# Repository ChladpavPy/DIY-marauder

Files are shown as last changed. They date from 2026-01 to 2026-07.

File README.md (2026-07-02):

# DIY Marauder

I have made this project because it was my first ever pcb project and I started with blueprint, I wanted something cool looking, like pentesting device for ethical hacking and as a experimental gadget that I could programm whatever way I wanted to do something cool and finally bring the code to life.

A custom macro keypad / pentesting node based on the Seeed XIAO ESP32S3 (originally designed for RP2040). Designed in KiCad and Fusion 360.

## Project Features

* **Microcontroller:** Seeed XIAO ESP32S3 (USB-C) *(Swapped from RP2040 due to delivery issues)*
* **Display:** 0.96" OLED (I2C) *(Swapped from 0.91")*
* **Controls:** 1x EC11 Rotary Encoder + 2x Mechanical MX Switches
* **Case:** Custom 3D printed snap-fit enclosure

## Gallery
### Build Preview
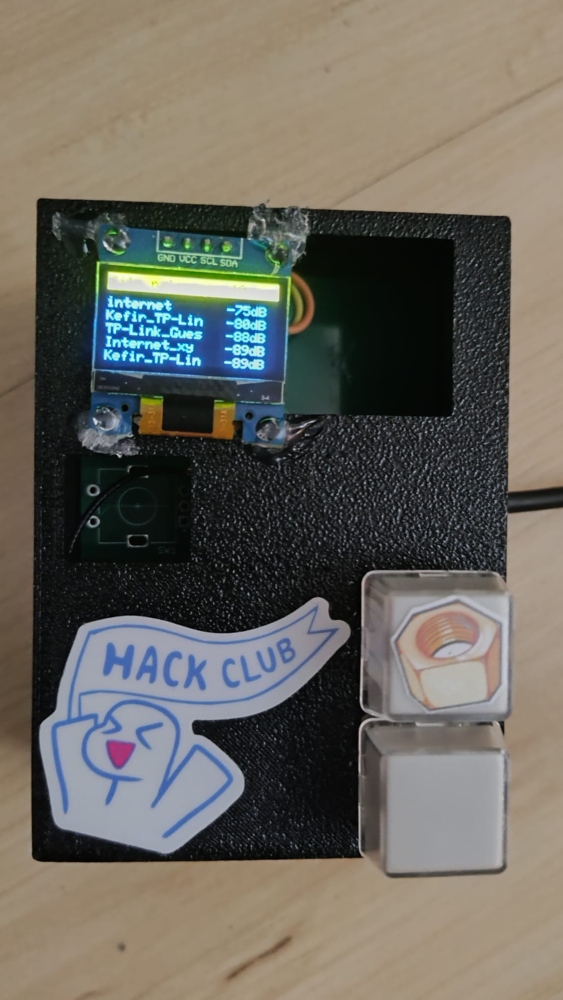
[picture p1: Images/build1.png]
Build preview

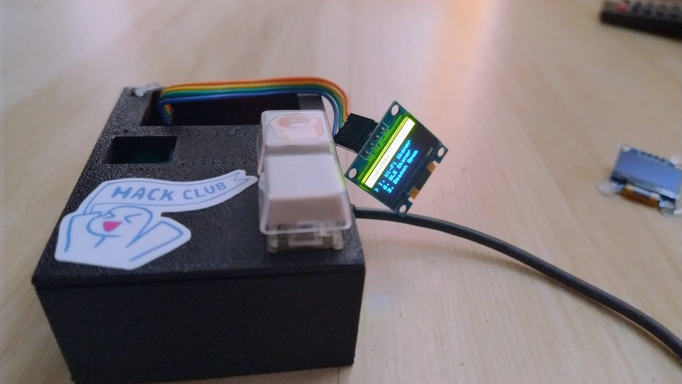
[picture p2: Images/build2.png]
Build preview

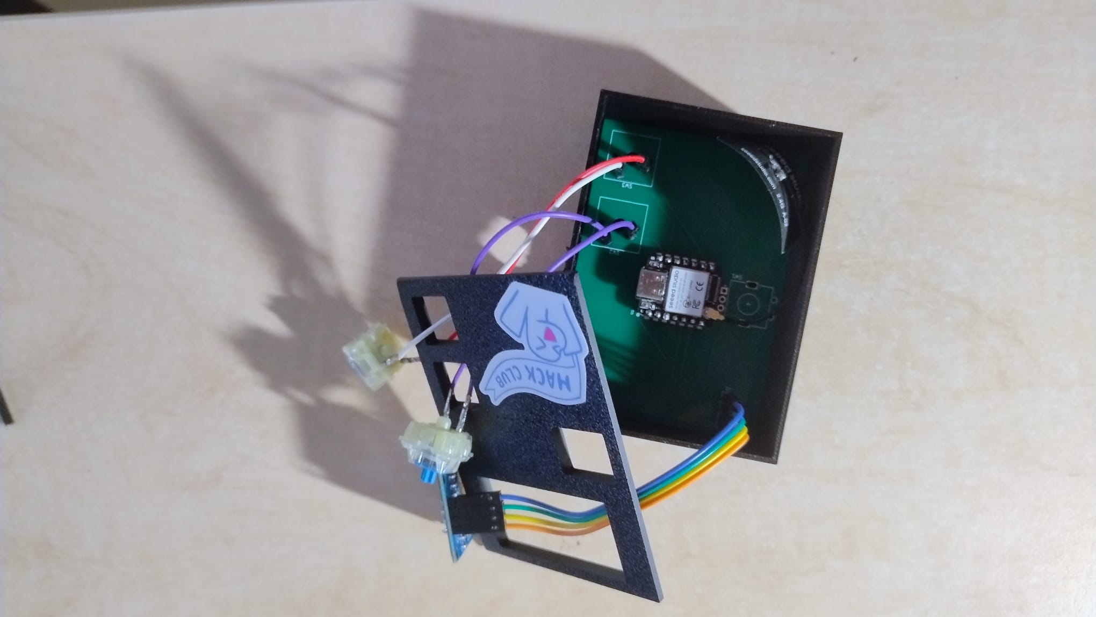
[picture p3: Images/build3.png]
Build preview


### Schematic
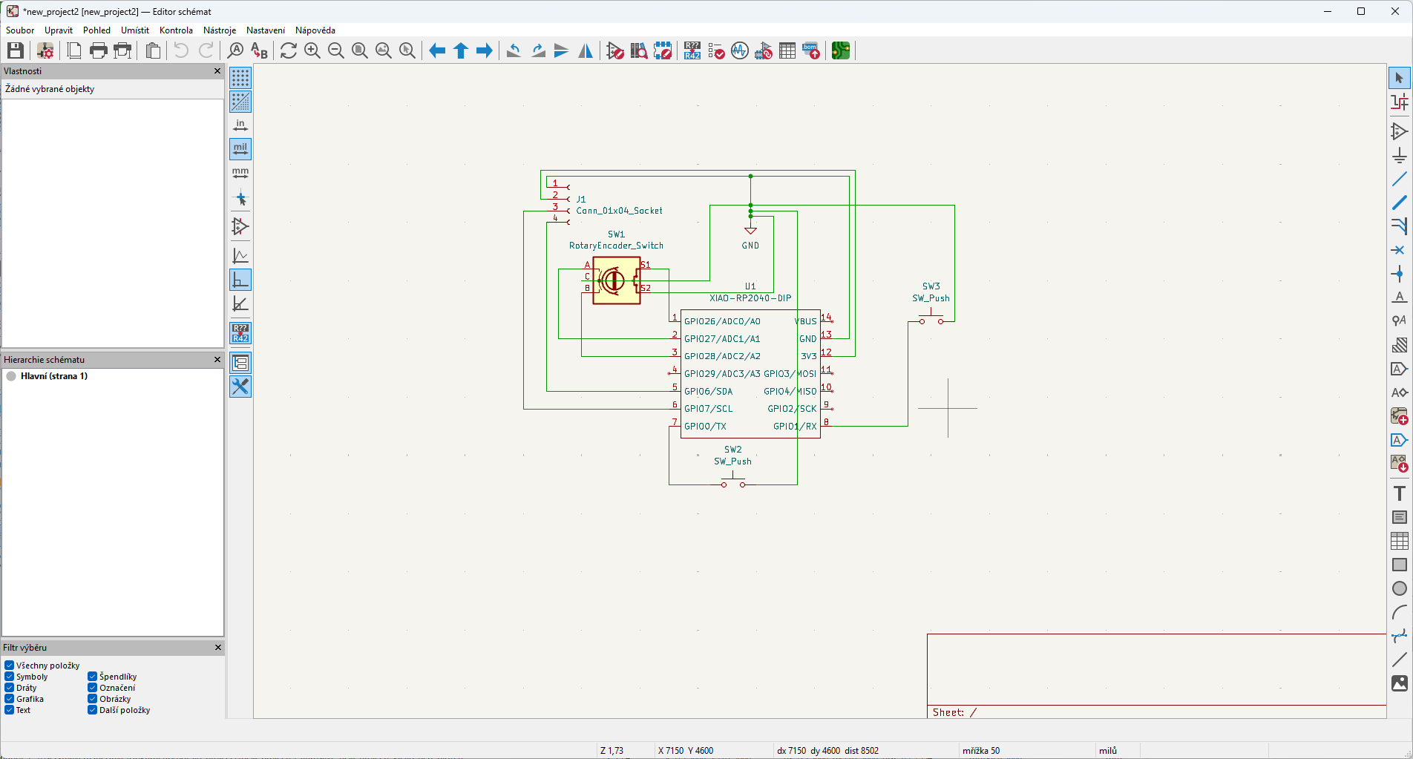
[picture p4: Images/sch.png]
Schematic


### PCB Routing
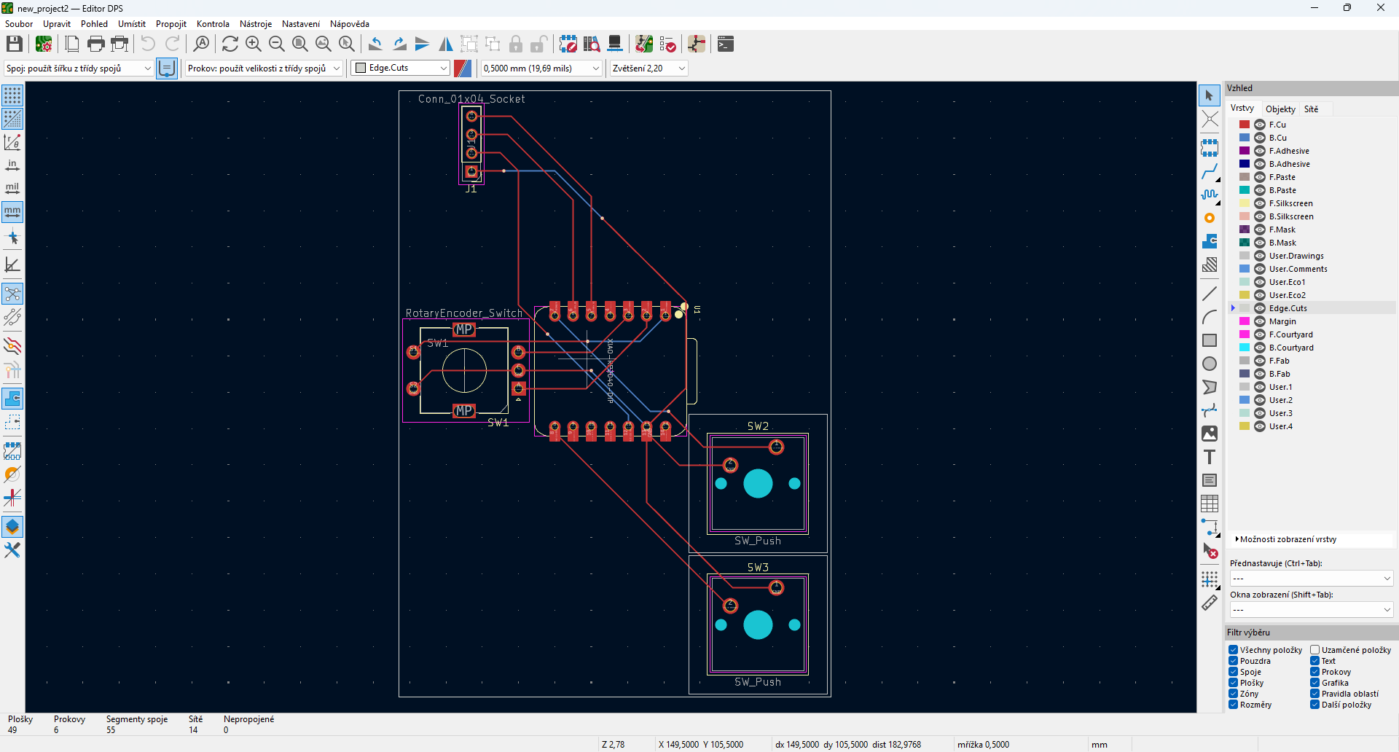
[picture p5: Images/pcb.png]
PCB 2D


### 3D PCB Render
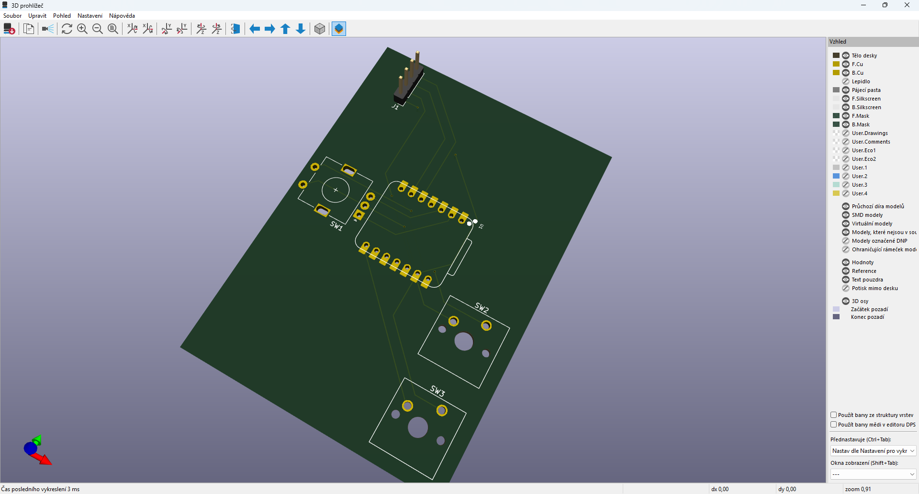
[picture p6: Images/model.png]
PCB 3D


### 3D Printed Case
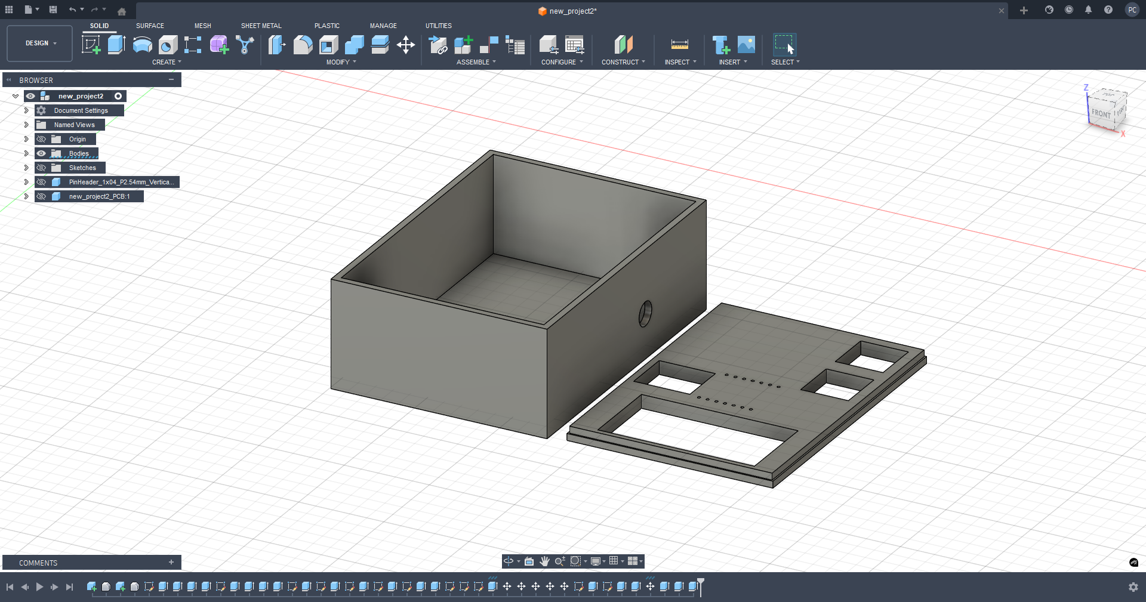
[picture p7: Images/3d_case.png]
Case


### Assembly Preview
The PCB fits perfectly inside the custom 3D printed case (designed with 0.4mm clearance).
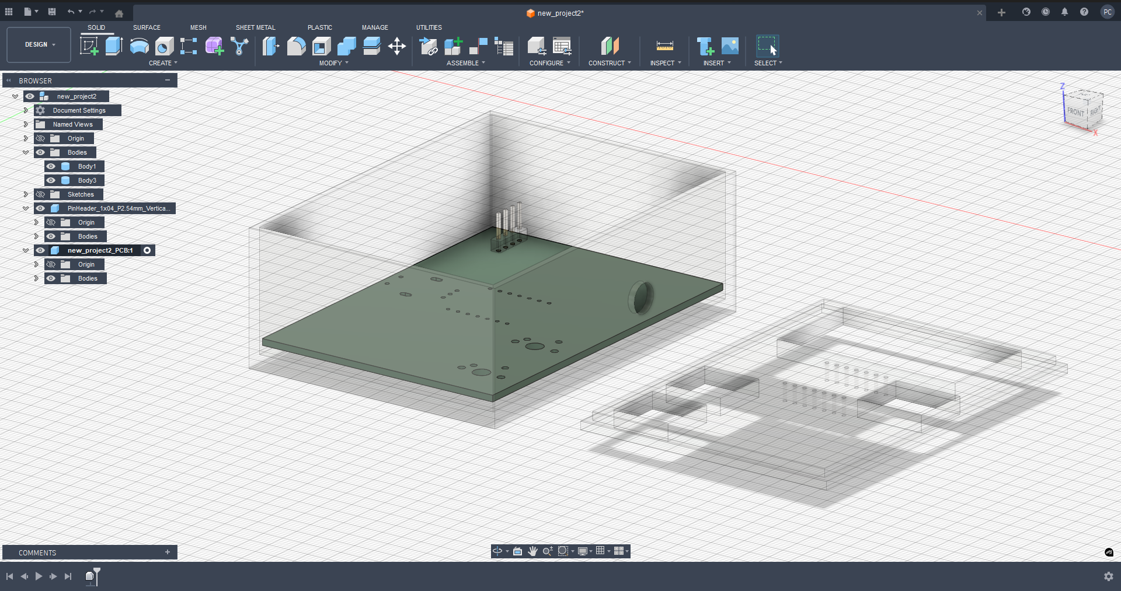
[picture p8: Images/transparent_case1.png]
Assembly Preview


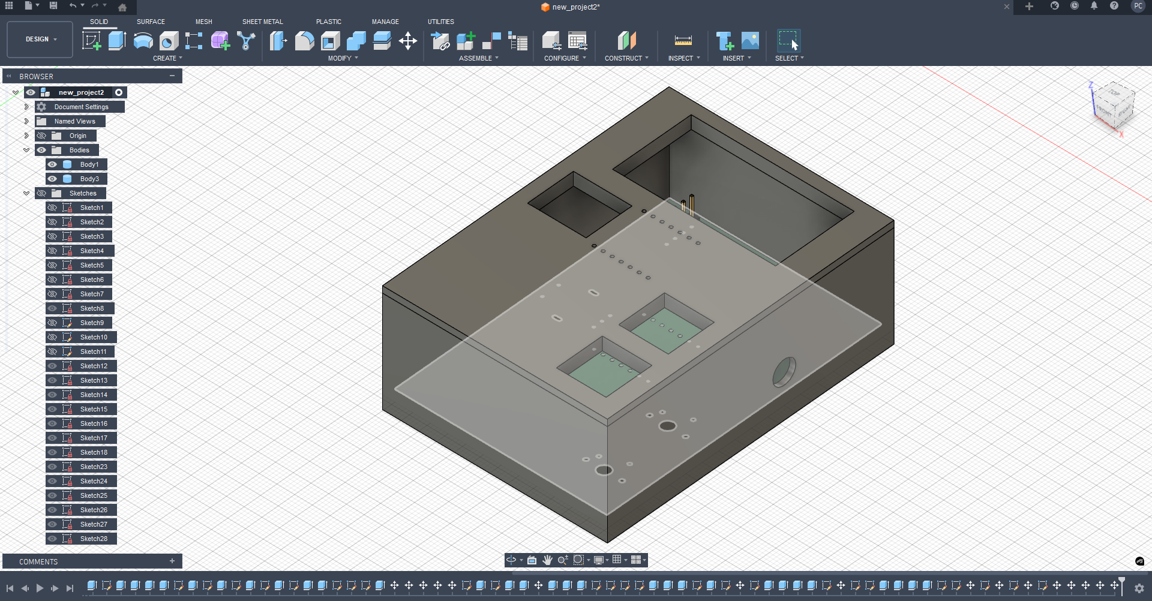
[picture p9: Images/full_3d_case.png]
Assembly_Preview2


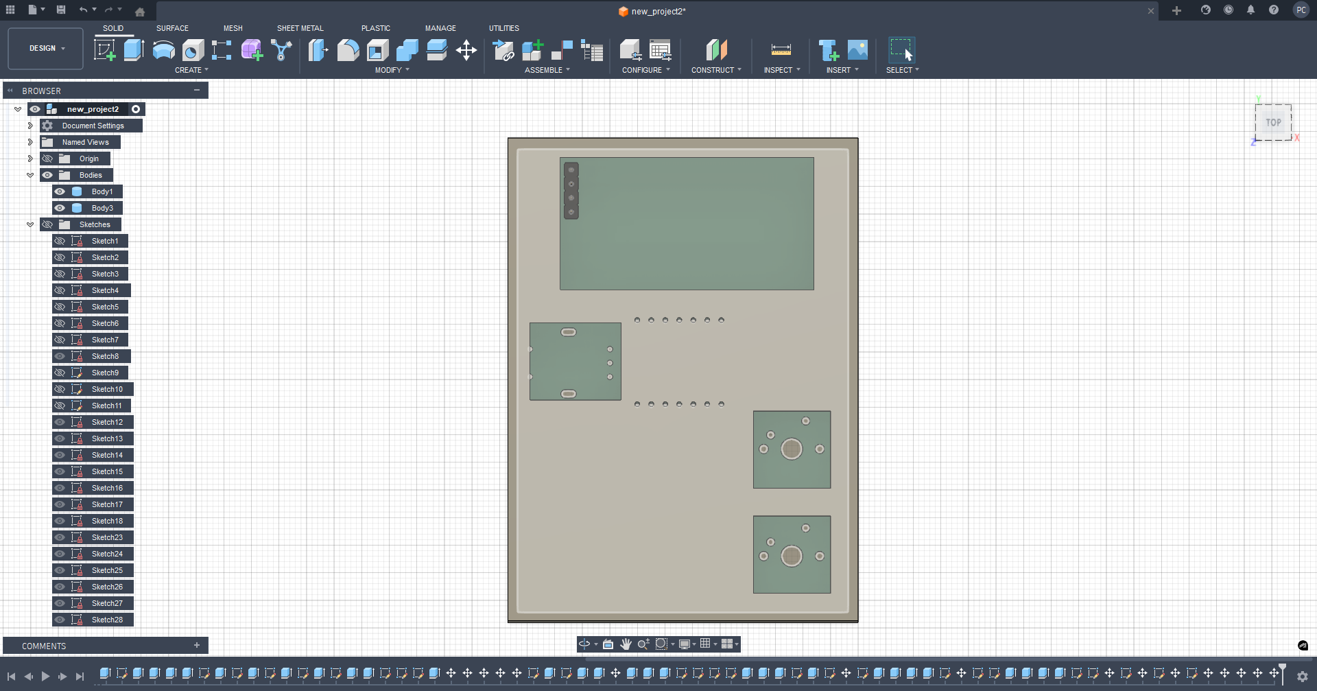
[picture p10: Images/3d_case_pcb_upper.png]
Assembly_Preview3


### Assembly Preview Seeed XIAO RP2040

Assembly Preview_xiao

Assembly Preview_xiao

Assembly Preview_xiao

Assembly Preview_xiao

Assembly Preview_xiao

Assembly Preview_xiao

---

Here is the updated BOM, previously I would have used XIAO RP2040, but since there was that customs delivery issues, I bought and used some of the remaining components from zeropad project

## Bill of Materials (BOM)

| Component | Qty | Purpose / Description | Price (USD) | Link / Distributor |
| :--- | :---: | :--- | :--- | :--- |
| **Seeed XIAO ESP32S3** | 1 | Microcontroller (Used instead of RP2040 due to delivery issues). | ~$7.50 | [Botland](https://botland.cz/moduly-wifi-a-bt-esp32/22878-seeed-xiao-esp32-s3-wifi-bluetooth-seeedstudio-113991114.html) |
| **0.96" I2C OLED Display** | 1 | Screen to show UI and analysis data (Swapped from 0.91"). | ~$2.00 | [AliExpress](https://a.aliexpress.com/_EGSrJ7g) |
| **EC11 Rotary Encoder** | 1 | Navigation control with push button. | ~$1.50 | [SparkFun](https://www.sparkfun.com/products/9117) |
| **Cherry MX Switches** | 2 | Secondary input buttons (Sourced from previous build). | ~$6.08 | [AliExpress](https://a.aliexpress.com/_EuLENRY) |
| **1U Blank Keycaps** | 2 | Standard covers for the mechanical switches. | ~$3.35 | [AliExpress](https://a.aliexpress.com/_Eyx6JJo) |
| **Knob** | 1 | Cap for the rotary encoder. | ~$1.50 | [SparkFun](https://www.sparkfun.com/products/10597) |
| **3D Printed Case** | 1 | Enclosure. Files in `3D_Models` folder. | $0.00 | printing legion |

---

## Folder Structure
* **Gerbers:** Manufacturing files ready for JLCPCB.
* **KiCad_Source:** Editable project files for KiCad.
* **3D_Models:** STL and STEP files for printing.

Journals - 
I am really sorry for the confusion, I thought that I was just submitting it for design review at first in stasis and I noticed it just now, however somehow it shows that it was submitted for build review, so I am adding the journals that I wanted to write in stasis there with time - I hope that it will be okay like this and also thank you for the review! : Journals - 

1. journal - soldering and first testing - 4 hours

Before that I have obviously spent a lot of time witch searching the cheapest esp32s3 xiao, which I could get, since these devices were not exatly cheap in czech republic or aliexpress and also wrote some firmware even before that although I still have not it working because I was still missing the keycaps and cherry mx switches which I used from the zeropad projet which arrived on monday, so I still had some time to build it.
I started by soldering everything. First I soldered the esp32-s3, but then I hit some major issues. I was struggling with how to mount the Cherry MX switches because the enclosure was so high and I needed them fixed at the top. It eventually hit me I could just place the switches in that top space and connect them from the bottom using jumper wires through the tht pads. So I soldered pin headers to the pcb on the bottom and then I soldered female jumpers to the switches and connected them. I did that twice.
After that I ran into another problem. Because of the postal service I did not have the encoder I ordered so I tried to scavenge one from around the house. I spent forever searching through the garage until I finally realized I could grab an encoder from an old grill. Finding the screwdriver to open it up in that messy garage was not easy but I managed to dismantle it only to realize it did not have any pins so it was absolutely useless. I just wasted my time.
Anyway I managed to get the display working. I used a pin header on the pcb and connected the screen via jumpers. After the hardware was somewhat assembled I had to actually make it do something useful. I did not want this to be just a simple script I wanted a standalone tool for network analysis. Since my plan to use a scavenged grill encoder failed I had to rely entirely on the two Cherry MX switches. This meant I could not just use a standard library for the menu so I had to write a custom UI system from scratch. I built a scrollable menu interface that dynamically adjusts to the oled screen. Writing a state machine for the button debouncing to handle both short and long presses took way more time than I expected but it was necessary to make the navigation feel responsive.
The firmware itself is around 1100 lines of c++ code. I implemented a wifi scanner and analyzer that scans 2.4ghz bands grabs rssi encryption types and mac addresses. I even added a visual channel analyzer to see where the interference is. Then I added a ble scanner to find bluetooth devices around and sort them by signal strength. Since this is meant to be portable I also implemented a deep sleep mode to save power when it is not actively scanning. Getting the display library to play nice with the specific i2c pins i routed on my pcb required some tweaking but once the display initialized it was satisfying.
Looking back considering this was my first pcb I did some pretty stupid things. I have no idea what I was thinking. First off I did not even realize i could use a gnd filled zone or plane so I just routed gnd traces everywhere but whatever it works. The real problem was the 3d case. For some reason I made a circular hole for the usb-c port not realizing I needed to fit the whole connector through it not just the cable. I literally just made a hole for the cable. Plus I placed the xiao in the middle of the board instead of at the edge so the usb-c port does not stick out properly which looks weird.
I had to fix the hole somehow. I tried sandpaper but that would have taken hours so I went for the radical solution. I grabbed a soldering iron and just ugly-melted the opening bigger despite breathing in all those plastic fumes. It did the trick and the cable fits now. Obviously I did not use my good soldering iron for that just an old destroyed one that was a year old anyway so it does not really matter.
Looking at the final build it is definitely a prototype. The hot glue and the missing encoder do not look professional but the core engineering is solid. I designed the pcb figured out the mechanical mounting for the switches and wrote a custom os for it. It works as a pocket-sized pentesting node. That wrapped up the soldering and assembly. I then started programming and testing the board but I will write about that in the next journal entry.

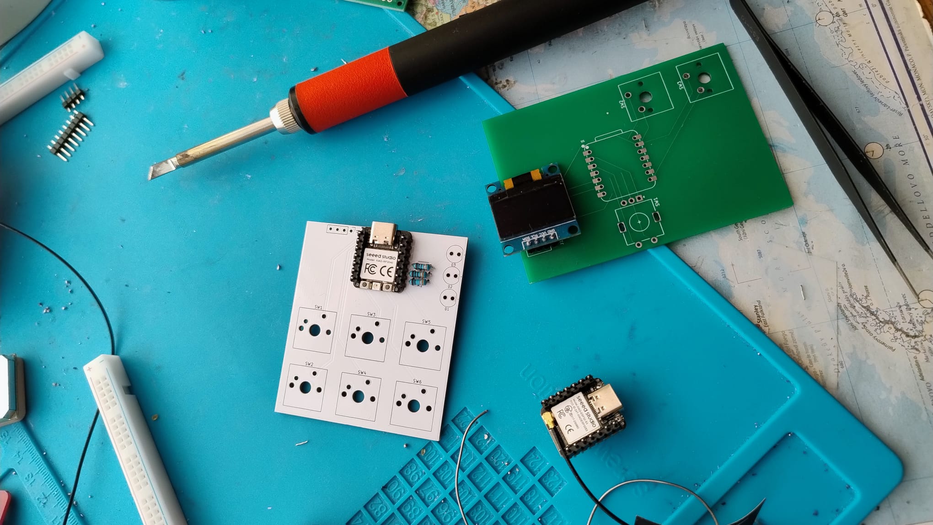
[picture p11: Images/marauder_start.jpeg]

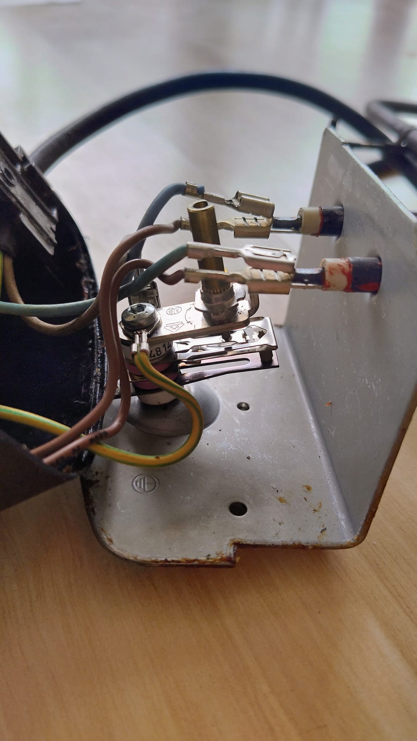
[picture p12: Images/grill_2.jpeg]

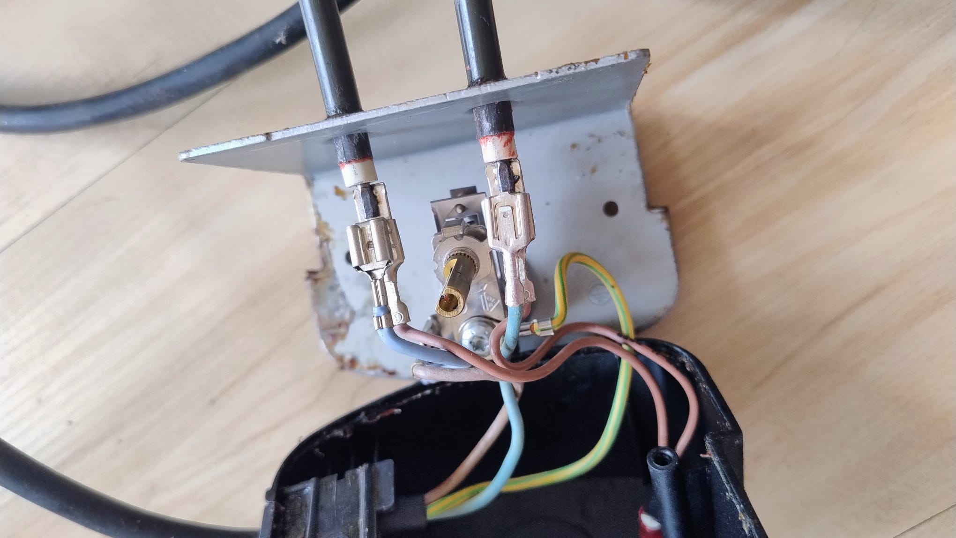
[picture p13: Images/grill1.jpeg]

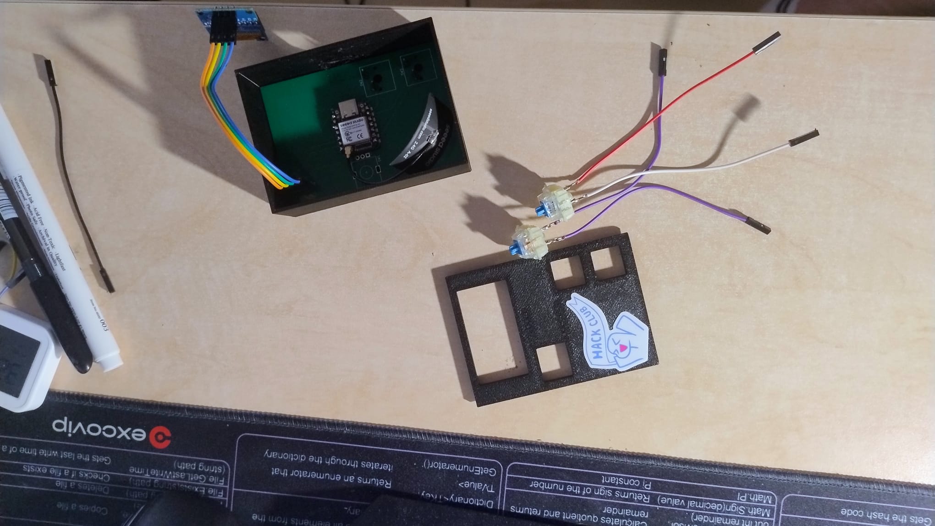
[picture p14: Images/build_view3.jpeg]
Build preview

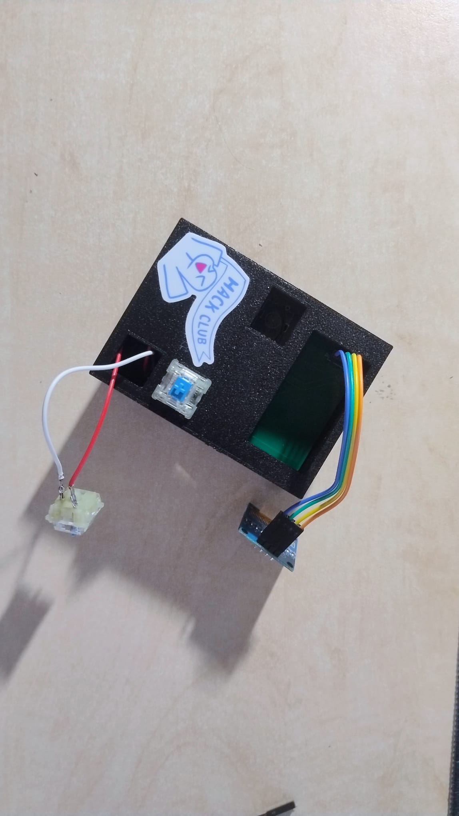
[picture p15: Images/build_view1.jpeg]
Build preview

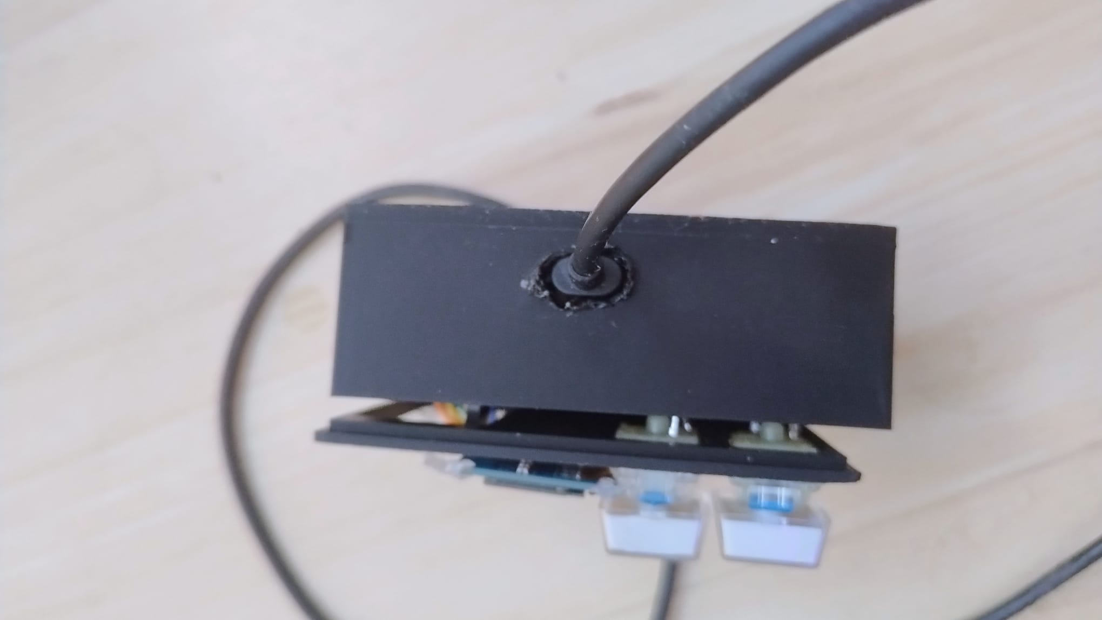
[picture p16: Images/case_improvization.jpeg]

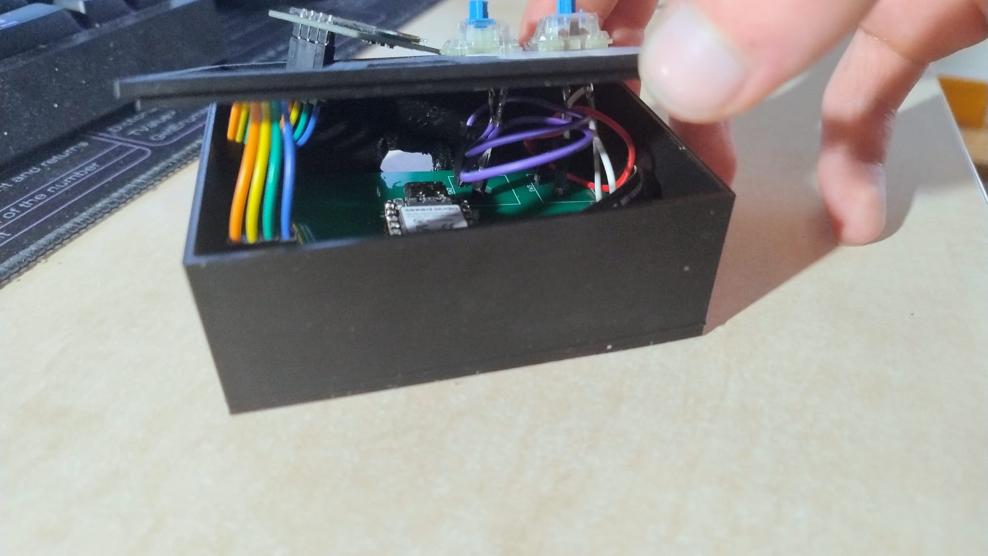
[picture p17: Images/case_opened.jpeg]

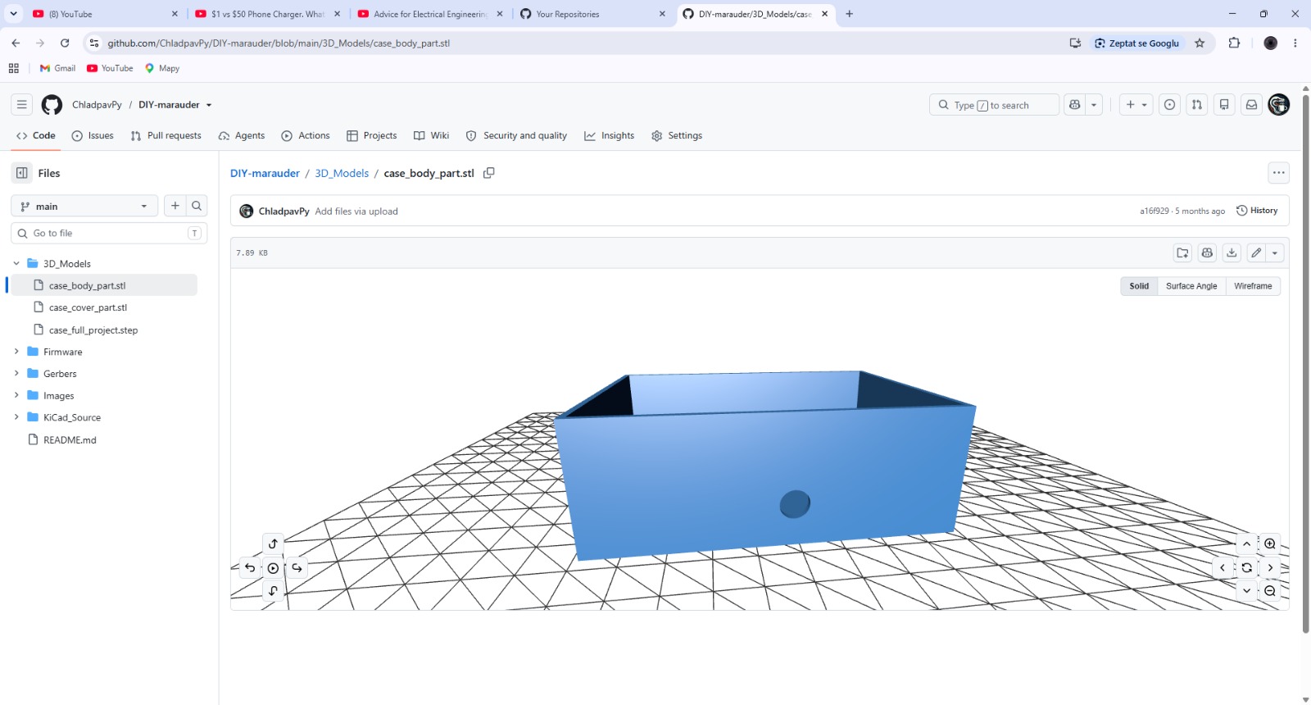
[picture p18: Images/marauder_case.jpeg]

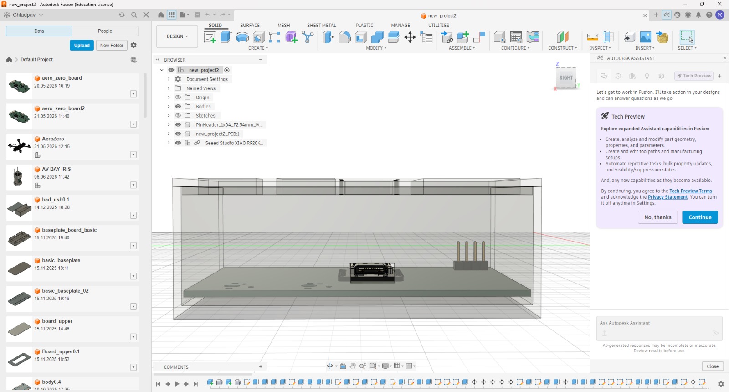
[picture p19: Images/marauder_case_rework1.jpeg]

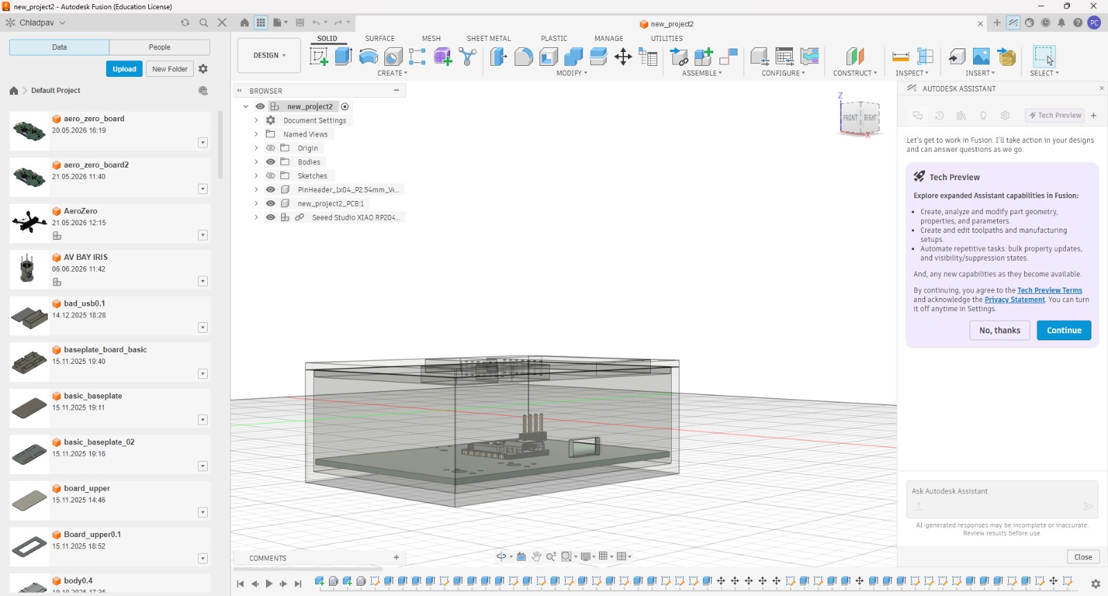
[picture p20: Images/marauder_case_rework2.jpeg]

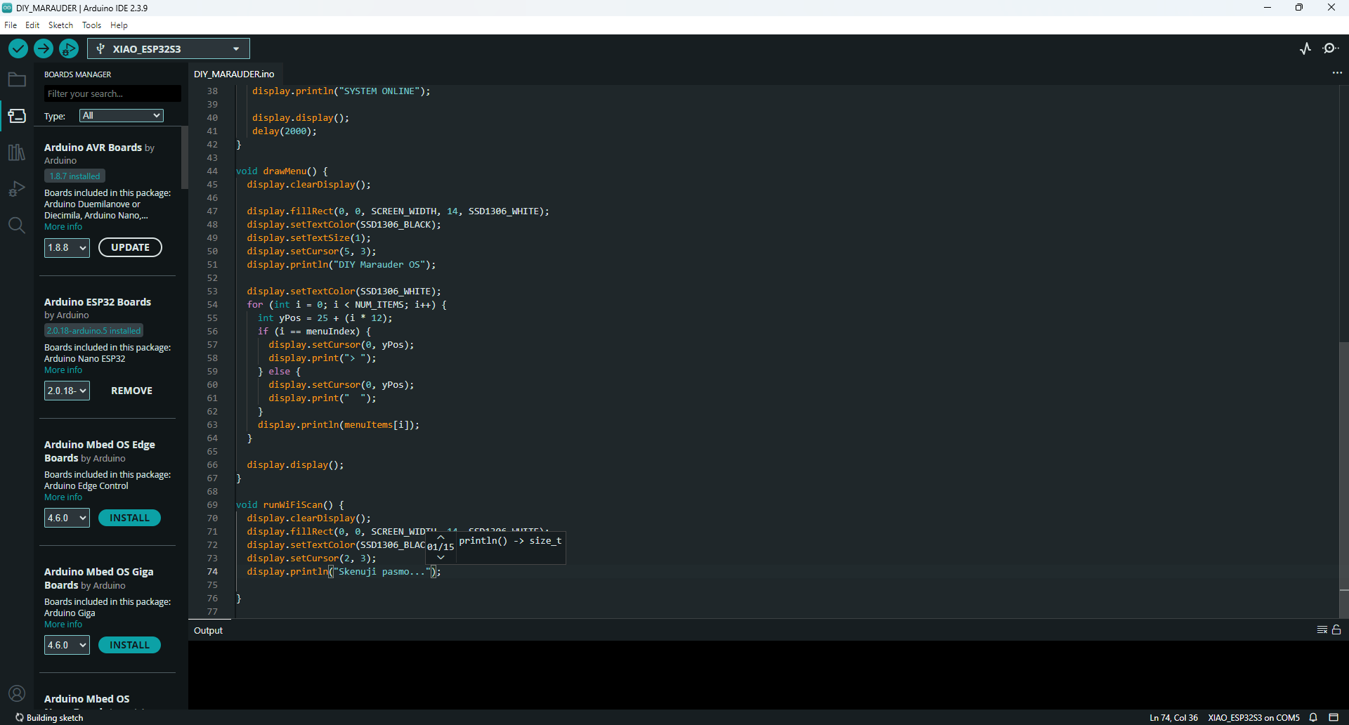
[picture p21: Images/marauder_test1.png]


2. journal - writing the firmware and flashing the device - 4 hours 20 minutes
After the hardware was somehow assembled, I had to actually make it do something useful. I did not want this to be just a simple script, I wanted a standalone tool for network analysis. Since my plan to use a scavenged grill encoder failed, I had to rely entirely on the two Cherry MX switches. This meant I could not just use a standard library for the menu, so I had to write a custom UI system from scratch. I built a scrollable menu interface that dynamically adjusts to the OLED screen. Writing a state machine for the button debouncing to handle both short and long presses took way more time than I expected, but it was necessary to make the navigation feel responsive.
The firmware itself is around 1100 lines of C++ code. I implemented a WiFi scanner and analyzer that scans 2.4GHz bands, grabs RSSI, encryption types and MAC addresses. I even added a visual channel analyzer to see where the interference is. Then I added a BLE scanner to find Bluetooth devices around and sort them by signal strength. Since this is meant to be portable, I also implemented a deep sleep mode to save power when it is not actively scanning. Getting the display library to play nice with the specific I2C pins I routed on my PCB required some tweaking, but once the display initialized, it was incredibly satisfying. Looking at the final build, it is definitely a prototype. The hot glue and the missing encoder do not look exactly professional, but the core engineering is solid. I designed the PCB, figured out the mechanical mounting for the switches, and wrote a completely custom OS for it. It works good as a pocket sized pentesting device and even integrated a encoder detection system since I have not got encoder to make it work although I dont have it. I am actually also really amazed what you can actually do with just a esp32 with just 7 pins and also with small 0.96 inch display
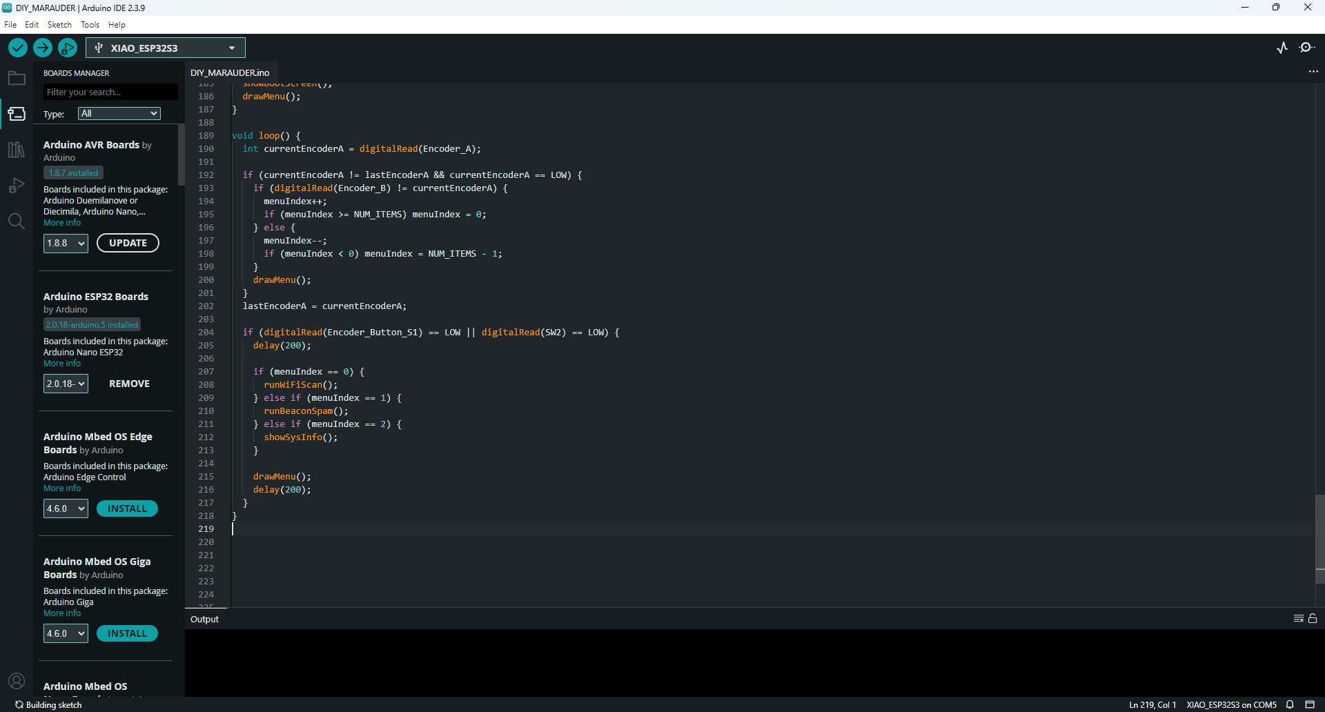
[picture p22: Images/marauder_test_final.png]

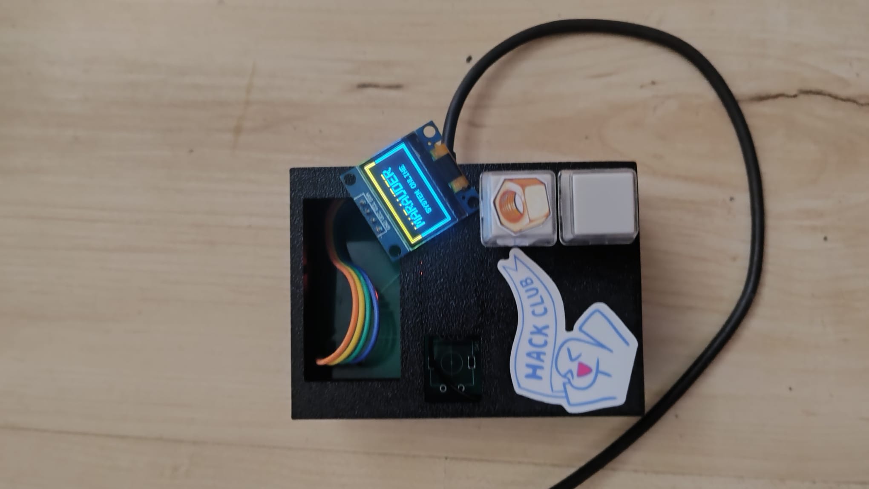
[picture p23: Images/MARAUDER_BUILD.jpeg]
Build preview

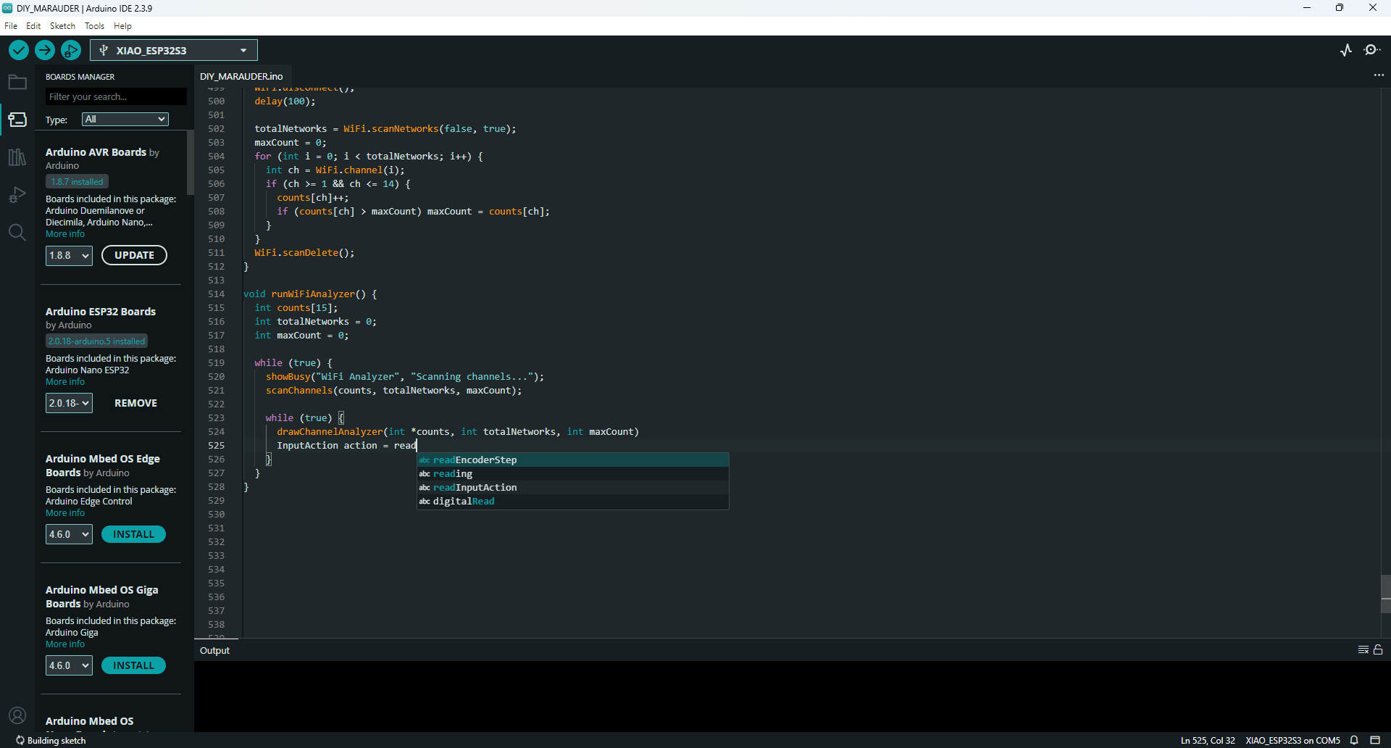
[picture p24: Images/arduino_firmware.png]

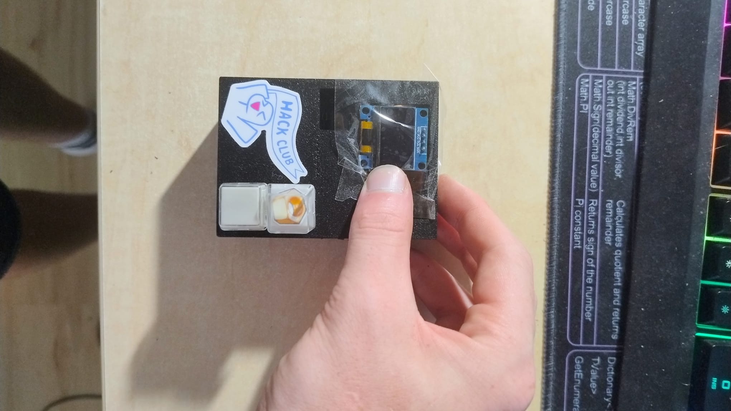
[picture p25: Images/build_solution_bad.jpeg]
Build preview

Build preview
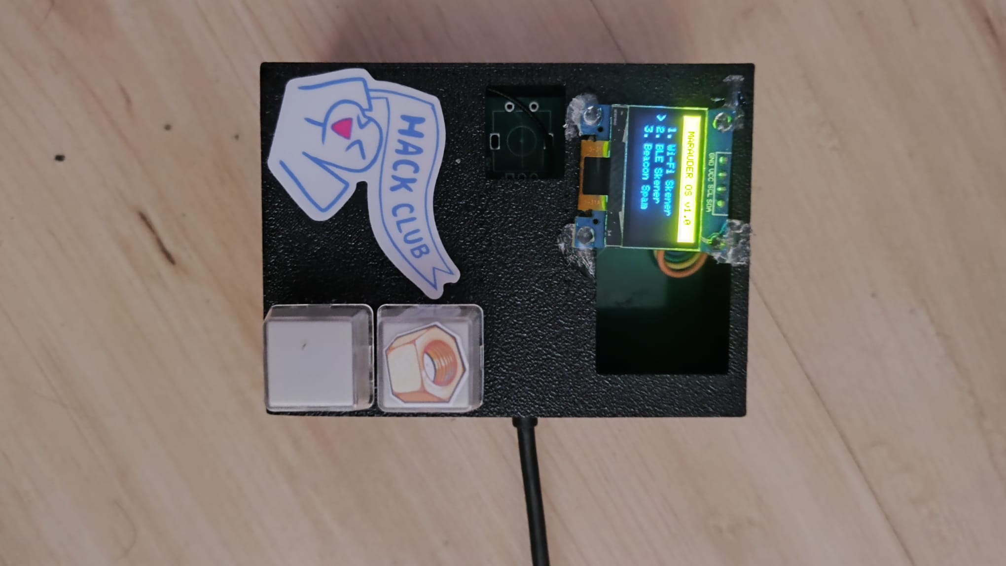
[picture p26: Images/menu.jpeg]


also regarding the BOM in readme I did not have there links before since it should have been shipped from hacklub HQ, but actually updated them and added them because I have used different parts, which was caused by the delivery problems, the only difference would be probably just the performance and that I would not have access to wifi functions with RP2040 otherwise the firmware should be suitable for both devices. - this was a HACKPAD

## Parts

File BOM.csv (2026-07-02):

Component | Qty | Purpose / Description | Price (USD) | Link / Distributor
Seeed XIAO ESP32S3 | 1 | Microcontroller (Used instead of RP2040 due to delivery issues) | ~$7.50 | https://botland.cz/moduly-wifi-a-bt-esp32/22878-seeed-xiao-esp32-s3-wifi-bluetooth-seeedstudio-113991114.html
0.96 I2C OLED Display | 1 | Screen to show UI and analysis data (Swapped from 0.91 inch). | ~$2.00 | https://a.aliexpress.com/_EGSrJ7g
EC11 Rotary Encoder | 1 | Navigation control with push button. | ~$1.50 | https://www.sparkfun.com/products/9117
Cherry MX Switches | 2 | Secondary input buttons (Sourced from previous build). | ~$6.08 | https://a.aliexpress.com/_EuLENRY
1U Blank Keycaps | 2 | Standard covers for the mechanical switches. | ~$3.35 | https://a.aliexpress.com/_Eyx6JJo
Knob | 1 | Cap for the rotary encoder. | ~$1.50 | https://www.sparkfun.com/products/10597
3D Printed Case | 1 | Enclosure. Files in 3D_Models folder. | $0.00 | printing legion

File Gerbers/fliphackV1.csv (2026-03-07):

Source: | C:\Users\pavel\OneDrive\Plocha\Fliphack_project\fliphackV1.kicad_sch
Date: | 2026-03-07T07:47:05+0100
Tool: | Eeschema 9.0.6
Generator: | G:\Games\bin\scripting\plugins/bom_csv_grouped_by_value.py
Component Count: | 60
Collated Components:
Item | Qty | Reference(s) | Value | LibPart | Footprint | Datasheet | DNP | Datasheet | Description | Footprint | LCSC | MNF PART NUMBER | PARTNO | Sim.Device | Sim.Pins | TEXT
1 | 1 | +3V3 | +3V3 | Connector:TestPoint | TestPoint:TestPoint_Pad_D1.0mm | ~ |  | ~ | test point | TestPoint:TestPoint_Pad_D1.0mm
2 | 1 | BZ1 | Buzzer | Device:Buzzer | Buzzer_Beeper:Buzzer_12x9.5RM7.6 | ~ |  | ~ | Buzzer, polarized | Buzzer_Beeper:Buzzer_12x9.5RM7.6
3 | 11 | C1, C2, C6, C7, C8, C9, C11, C12, C13, C20, C36 | 10uF | Device:C | Capacitor_SMD:C_0402_1005Metric | ~ |  | ~ | Unpolarized capacitor | Capacitor_SMD:C_0402_1005Metric | C15525 | C15525
4 | 3 | C3, C4, C10 | 100nF | Device:C | Capacitor_SMD:C_0402_1005Metric | ~ |  | ~ | Unpolarized capacitor | Capacitor_SMD:C_0402_1005Metric | C1525 | C1525
5 | 1 | C5 | 1uF | Device:C | Capacitor_SMD:C_0402_1005Metric | ~ |  | ~ | Unpolarized capacitor | Capacitor_SMD:C_0402_1005Metric | C52923 | C52923
6 | 2 | C22, C35 | 0.1uF | Device:C | Capacitor_SMD:C_0402_1005Metric | ~ |  | ~ | Unpolarized capacitor | Capacitor_SMD:C_0402_1005Metric | C1525 | C1525
7 | 1 | D1 | LED | Device:LED | LED_SMD:LED_0603_1608Metric | ~ |  | ~ | Light emitting diode | LED_SMD:LED_0603_1608Metric | C2286 | C2286
8 | 1 | D4 | SS14 | Diode:SS14 | Diode_SMD:D_SMA | https://www.vishay.com/docs/88746/ss12.pdf |  | https://www.vishay.com/docs/88746/ss12.pdf | 40V 1A Schottky Diode, SMA | Diode_SMD:D_SMA | C2480 | C2480
9 | 2 | D7, D8 | IR LED | :LED_1 | LED_THT:LED_D5.0mm | ~ |  | ~ | Light emitting diode | LED_THT:LED_D5.0mm |  |  |  |  | 1=K 2=A
10 | 1 | Flash1 | Flash | Switch:SW_Push | Button_Switch_SMD:SW_Push_1P1T_XKB_TS-1187A | ~ |  | ~ | Push button switch, generic, two pins | Button_Switch_SMD:SW_Push_1P1T_XKB_TS-1187A | C318884 | C318884
11 | 1 | GND1 | GND | Connector:TestPoint | TestPoint:TestPoint_Pad_D1.0mm | ~ |  | ~ | test point | TestPoint:TestPoint_Pad_D1.0mm
12 | 1 | J1 | USB_C_Receptacle_USB2.0_14P | Connector:USB_C_Receptacle_USB2.0_14P | Connector_USB:USB_C_Receptacle_HCTL_HC-TYPE-C-16P-01A | https://www.usb.org/sites/default/files/documents/usb_type-c.zip |  | https://www.usb.org/sites/default/files/documents/usb_type-c.zip | USB 2.0-only 14P Type-C Receptacle connector | Connector_USB:USB_C_Receptacle_HCTL_HC-TYPE-C-16P-01A | C19274016 | C19274016
13 | 1 | J2 | Conn_01x02_Pin | Connector:Conn_01x02_Pin | Connector_PinSocket_2.54mm:PinSocket_1x02_P2.54mm_Vertical | ~ |  | ~ | Generic connector, single row, 01x02, script generated | Connector_PinSocket_2.54mm:PinSocket_1x02_P2.54mm_Vertical
14 | 1 | J4 | J_NRF24 | Connector_Generic:Conn_02x04_Odd_Even | Connector_PinHeader_2.54mm:PinHeader_2x04_P2.54mm_Vertical | ~ |  | ~ | Generic connector, double row, 02x04, odd/even pin numbering scheme (row 1 odd numbers, row 2 even numbers), script generated (kicad-library-utils/schlib/autogen/connector/) | Connector_PinHeader_2.54mm:PinHeader_2x04_P2.54mm_Vertical
15 | 1 | J6 | CC1101_Module | Connector_Generic:Conn_02x04_Odd_Even | Connector_PinHeader_2.54mm:PinHeader_2x04_P2.54mm_Vertical | ~ |  | ~ | Generic connector, double row, 02x04, odd/even pin numbering scheme (row 1 odd numbers, row 2 even numbers), script generated (kicad-library-utils/schlib/autogen/connector/) | Connector_PinHeader_2.54mm:PinHeader_2x04_P2.54mm_Vertical
16 | 1 | J9 | NFC_PN532 | Connector:Conn_01x04_Pin | Connector_PinHeader_2.54mm:PinHeader_1x04_P2.54mm_Vertical | ~ |  | ~ | Generic connector, single row, 01x04, script generated | Connector_PinHeader_2.54mm:PinHeader_1x04_P2.54mm_Vertical
17 | 1 | J10 | SD_Card_Module | Connector:Conn_01x06_Pin | Connector_PinHeader_2.54mm:PinHeader_1x06_P2.54mm_Vertical | ~ |  | ~ | Generic connector, single row, 01x06, script generated | Connector_PinHeader_2.54mm:PinHeader_1x06_P2.54mm_Vertical
18 | 1 | J11 | 1.69 inch IPS TFT LCD Display Module ST7789 SPI | Connector:Conn_01x08_Pin | Connector_PinHeader_2.54mm:PinHeader_1x08_P2.54mm_Vertical | ~ |  | ~ | Generic connector, single row, 01x08, script generated | Connector_PinHeader_2.54mm:PinHeader_1x08_P2.54mm_Vertical |  |  |  |  |  | TFT_RST
19 | 1 | J12 | NEO-6M GPS Module | Connector:Conn_01x04_Pin | Connector_PinHeader_2.54mm:PinHeader_1x04_P2.54mm_Vertical | ~ |  | ~ | Generic connector, single row, 01x04, script generated | Connector_PinHeader_2.54mm:PinHeader_1x04_P2.54mm_Vertical
20 | 1 | Q1 | AO3401A | Transistor_FET:AO3401A | Package_TO_SOT_SMD:SOT-23 | http://www.aosmd.com/pdfs/datasheet/AO3401A.pdf |  | http://www.aosmd.com/pdfs/datasheet/AO3401A.pdf | -4.0A Id, -30V Vds, P-Channel MOSFET, SOT-23 | Package_TO_SOT_SMD:SOT-23 | C15127 | C15127
21 | 2 | Q2, Q3 | AO3400A | Transistor_FET:Q_NMOS_GSD | Package_TO_SOT_SMD:SOT-23 | ~ |  | ~ | N-MOSFET transistor, gate/source/drain | Package_TO_SOT_SMD:SOT-23 | C20917 | C20917
22 | 2 | R1, R15 | 2K | Device:R | Resistor_SMD:R_0402_1005Metric | ~ |  | ~ | Resistor | Resistor_SMD:R_0402_1005Metric | C4109 | C4109
23 | 2 | R2, R18 | 0R | Device:R | Resistor_SMD:R_0402_1005Metric | ~ |  | ~ | Resistor | Resistor_SMD:R_0402_1005Metric | C17168 | C17168
24 | 2 | R3, R5 | 100R | Device:R | Resistor_SMD:R_0402_1005Metric | ~ |  | ~ | Resistor | Resistor_SMD:R_0402_1005Metric | C25076 | C25076
25 | 4 | R4, R11, R13, R21 | 10K | Device:R | Resistor_SMD:R_0402_1005Metric | ~ |  | ~ | Resistor | Resistor_SMD:R_0402_1005Metric | C25744 | C25744
26 | 2 | R8, R9 | 4.7R | Device:R | Resistor_SMD:R_0805_2012Metric | ~ |  | ~ | Resistor | Resistor_SMD:R_0805_2012Metric | C17675 | C17675
27 | 2 | R12, R19 | 200K | Device:R | Resistor_SMD:R_0402_1005Metric | ~ |  | ~ | Resistor | Resistor_SMD:R_0402_1005Metric | C25764 | C25764
28 | 2 | R14, R17 | 5.1K | Device:R | Resistor_SMD:R_0402_1005Metric | ~ |  | ~ | Resistor | Resistor_SMD:R_0402_1005Metric | C25905 | C25905
29 | 1 | R20 | 100K | Device:R | Resistor_SMD:R_0402_1005Metric | ~ |  | ~ | Resistor | Resistor_SMD:R_0402_1005Metric | C25741 | C25741
30 | 1 | Reset2 | Reset | Switch:SW_Push | Button_Switch_SMD:SW_Push_1P1T_XKB_TS-1187A | ~ |  | ~ | Push button switch, generic, two pins | Button_Switch_SMD:SW_Push_1P1T_XKB_TS-1187A | C318884 | C318884
31 | 1 | SW1 | SW_SP5T_NR01105 | Switch:SW_SP5T_NR01105 | Button_Switch_THT:SW_NKK_NR01 | https://www.nkkswitches.com/pdf/NR01%20Rotaries.pdf |  | https://www.nkkswitches.com/pdf/NR01%20Rotaries.pdf | NKK Switches NR01 Series rotary SP5T switch | Button_Switch_THT:SW_NKK_NR01 | C2858286 | C2858286
32 | 1 | U1 | ESP32-S3-WROOM-1U | RF_Module:ESP32-S3-WROOM-1 | RF_Module:ESP32-S3-WROOM-1U | https://www.espressif.com/sites/default/files/documentation/esp32-s3-wroom-1_wroom-1u_datasheet_en.pdf |  | https://www.espressif.com/sites/default/files/documentation/esp32-s3-wroom-1_wroom-1u_datasheet_en.pdf | RF Module, ESP32-S3 SoC, Wi-Fi 802.11b/g/n, Bluetooth, BLE, 32-bit, 3.3V, onboard antenna, SMD | RF_Module:ESP32-S3-WROOM-1U | C3013946 | C3013946
33 | 1 | U2 | TSOP38438 | Interface_Optical:TSOP384xx | OptoDevice:Vishay_MINICAST-3Pin | http://www.vishay.com/docs/82491/tsop382.pdf |  | http://www.vishay.com/docs/82491/tsop382.pdf | Photo Modules for PCM Remote Control Systems | OptoDevice:Vishay_MINICAST-3Pin
34 | 1 | U3 | MCP73831-2-OT | Battery_Management:MCP73831-2-OT | Package_TO_SOT_SMD:SOT-23-5 | http://ww1.microchip.com/downloads/en/DeviceDoc/20001984g.pdf |  | http://ww1.microchip.com/downloads/en/DeviceDoc/20001984g.pdf | Single cell, Li-Ion/Li-Po charge management controller, 4.20V, Tri-State Status Output, in SOT23-5 package | Package_TO_SOT_SMD:SOT-23-5 | C32574 | C32574
35 | 1 | U4 | USBLC6-2SC6 | Power_Protection:USBLC6-2SC6 | Package_TO_SOT_SMD:SOT-23-6 | https://www.st.com/resource/en/datasheet/usblc6-2.pdf |  | https://www.st.com/resource/en/datasheet/usblc6-2.pdf | Very low capacitance ESD protection diode, 2 data-line, SOT-23-6 | Package_TO_SOT_SMD:SOT-23-6 | C7519 | C7519
36 | 1 | U5 | XC6220B331MR | Regulator_Linear:XC6220B331MR | Package_TO_SOT_SMD:SOT-23-5 | https://www.torexsemi.com/file/xc6220/XC6220.pdf |  | https://www.torexsemi.com/file/xc6220/XC6220.pdf | 1A, Low Drop-out Voltage Regulator, Fixed Output 3.3V, SOT-23-5 | Package_TO_SOT_SMD:SOT-23-5 | C86534 | C86534

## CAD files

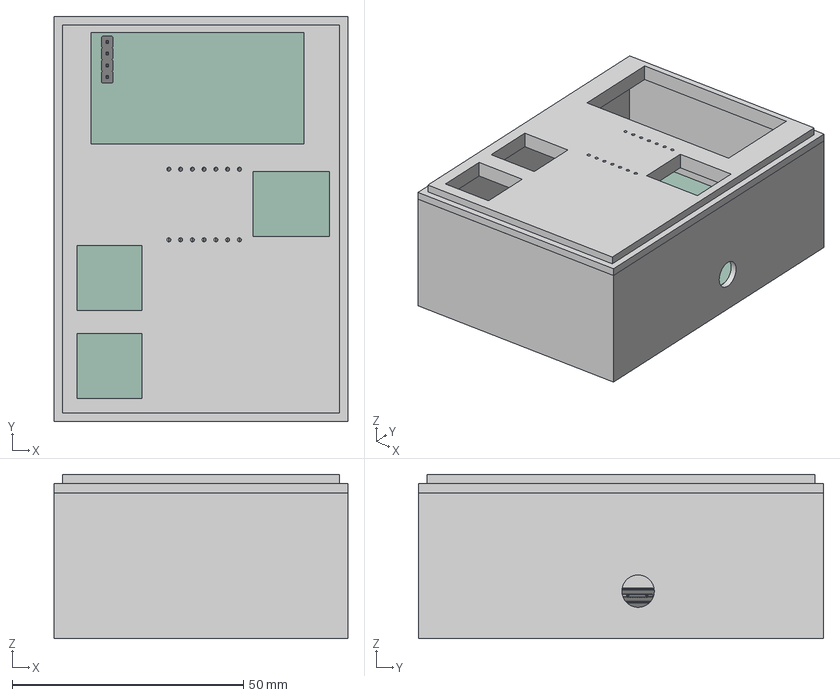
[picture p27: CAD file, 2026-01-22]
3D_Models/new_project2_full.step
63.5 x 87.5 x 35.5 mm

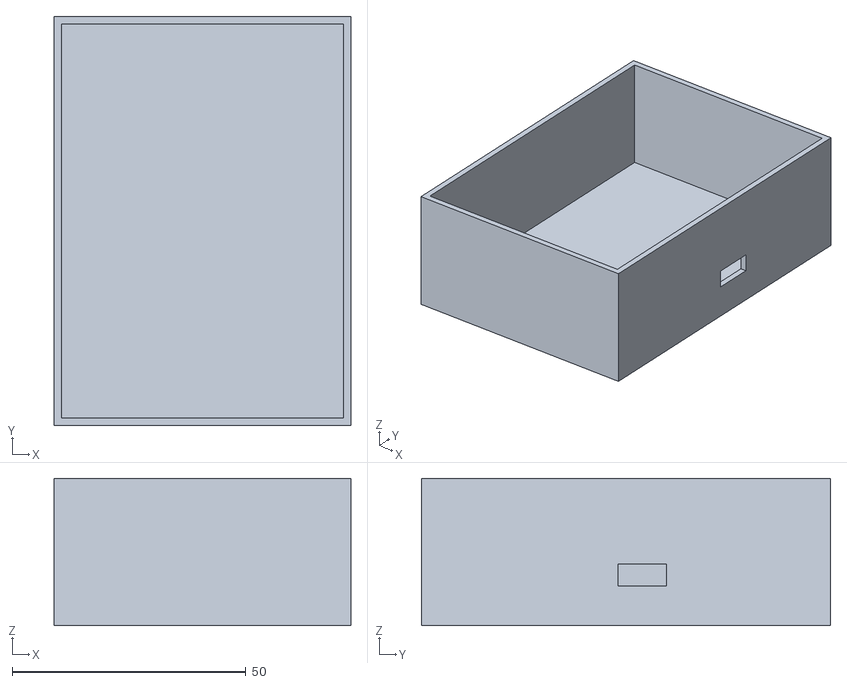
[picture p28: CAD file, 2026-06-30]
3D_Models/Body_repaired_BOTTOM.stl
63.5 x 87.5 x 31.5

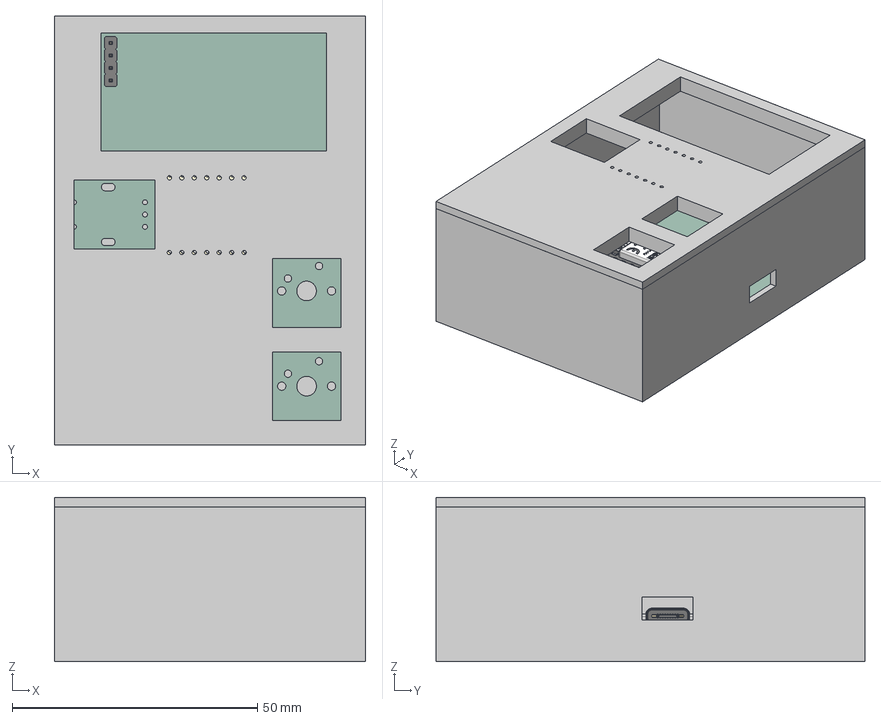
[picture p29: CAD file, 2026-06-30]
3D_Models/DIY_MARAUDER.step
63.5 x 87.5 x 33.5 mm

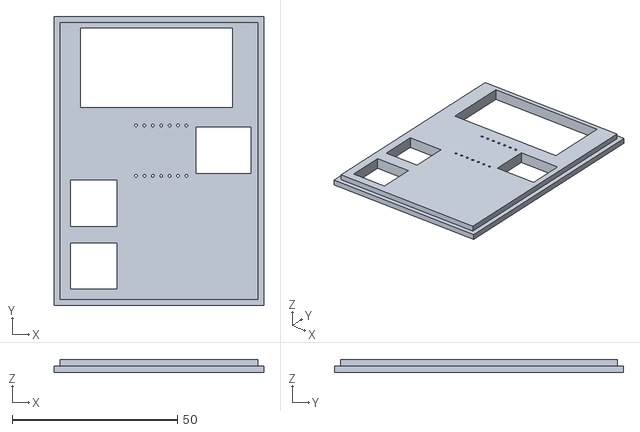
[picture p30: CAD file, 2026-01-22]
3D_Models/case_cover_part.stl
63.5 x 87.5 x 4.00

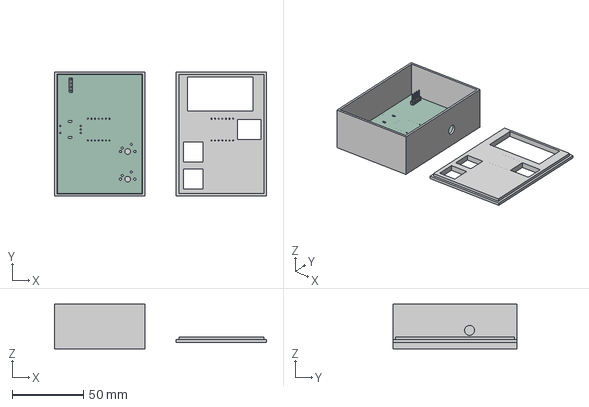
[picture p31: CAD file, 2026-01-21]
3D_Models/new_project2_fusion.step
149.1 x 87.5 x 31.5 mm

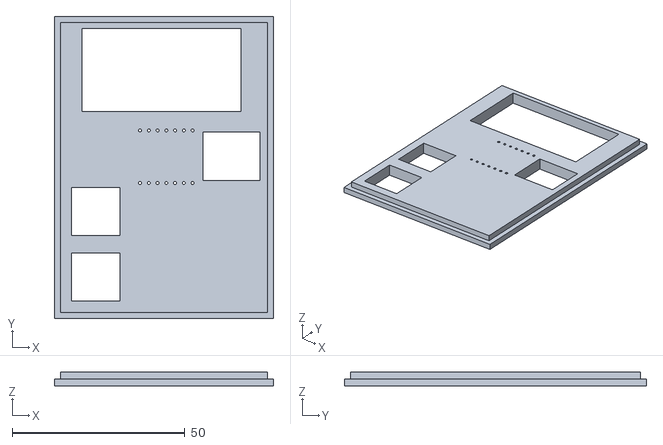
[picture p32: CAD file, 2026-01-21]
3D_Models/case_part_cover.stl
63.5 x 87.5 x 4.00

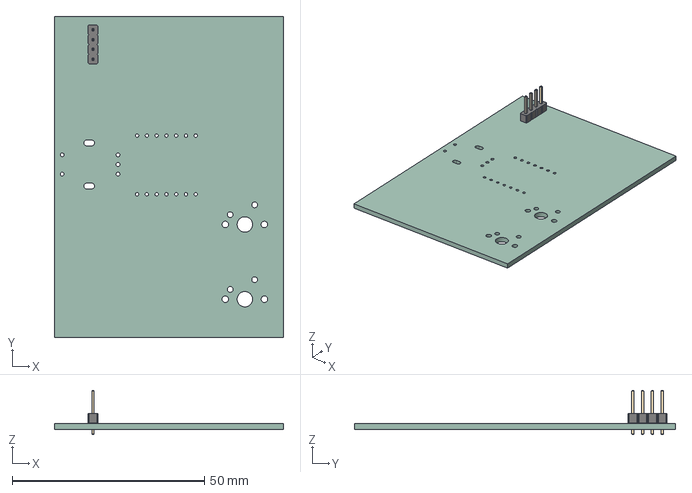
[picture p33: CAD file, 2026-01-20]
3D_Models/new_project2.step
59.5 x 83.5 x 11.5 mm
PinHeader_1x04_P2.54mm_Vertical
new_project2_PCB

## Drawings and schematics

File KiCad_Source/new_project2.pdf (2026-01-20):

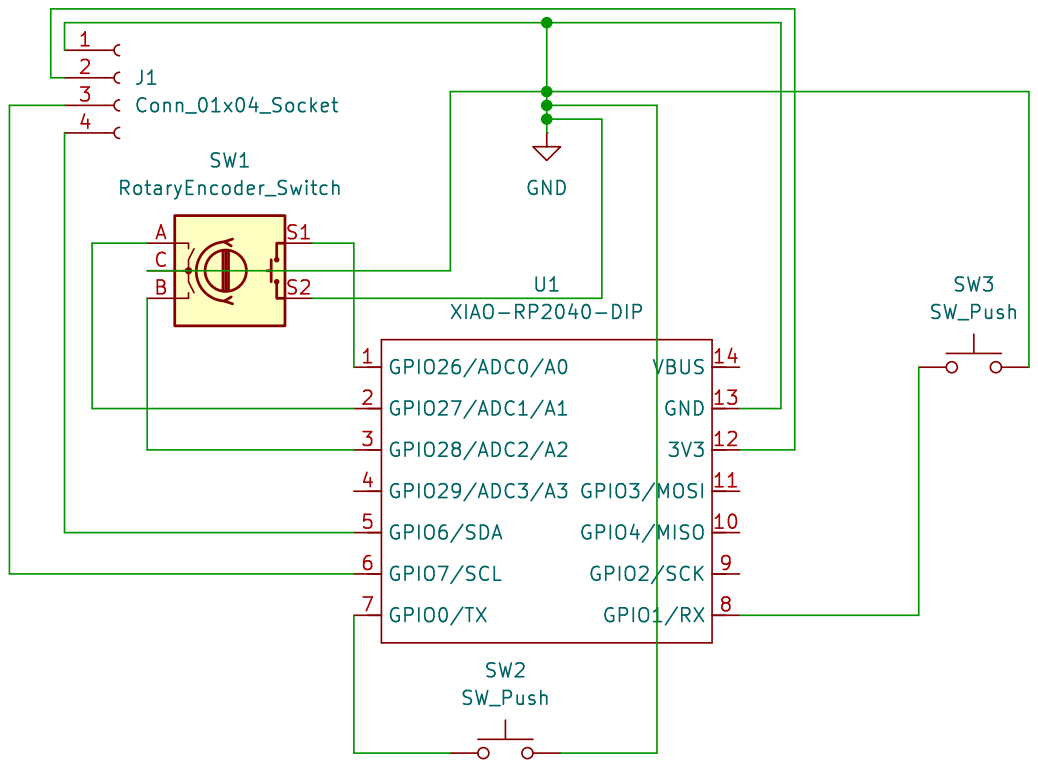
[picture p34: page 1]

Id: 1/1 Title: File: new_project2.kicad_sch Sheet: /

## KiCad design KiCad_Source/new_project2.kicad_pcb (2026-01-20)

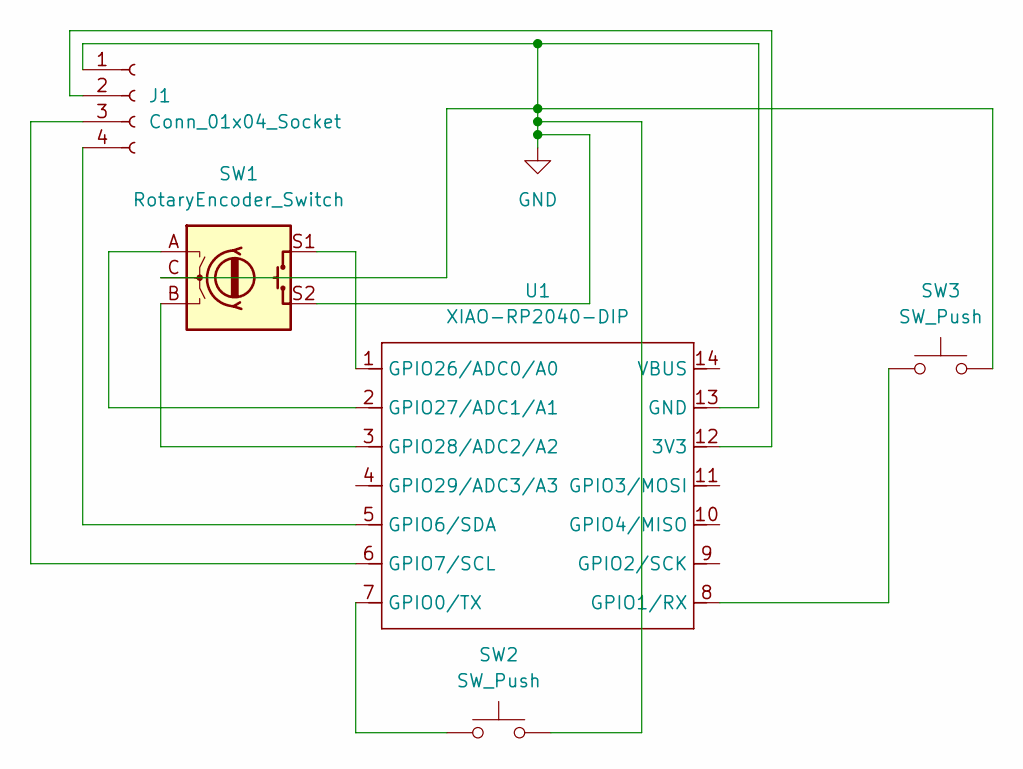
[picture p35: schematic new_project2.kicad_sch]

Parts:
J1: Conn_01x04_Socket; PinHeader_1x04_P2.54mm_Vertical
SW1: RotaryEncoder_Switch; RotaryEncoder_Alps_EC11E-Switch_Vertical_H20mm
SW2, SW3: SW_Push; SW_Cherry_MX_1.00u_PCB
U1: XIAO-RP2040-DIP

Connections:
GND: J1.1, SW1.C, SW1.S2, SW2.2, SW3.1, U1.13 (GND)
unnamed: J1.2, U1.12 (3V3)
unnamed: J1.3, U1.6 (GPIO7/SCL)
unnamed: J1.4, U1.5 (GPIO6/SDA)
unnamed: SW2.1, U1.7 (GPIO0/TX)
unnamed: SW3.2, U1.8 (GPIO1/RX)
unnamed: SW1.S1, U1.1 (GPIO26/ADC0/A0)
unnamed: SW1.A, U1.2 (GPIO27/ADC1/A1)
unnamed: SW1.B, U1.3 (GPIO28/ADC2/A2)

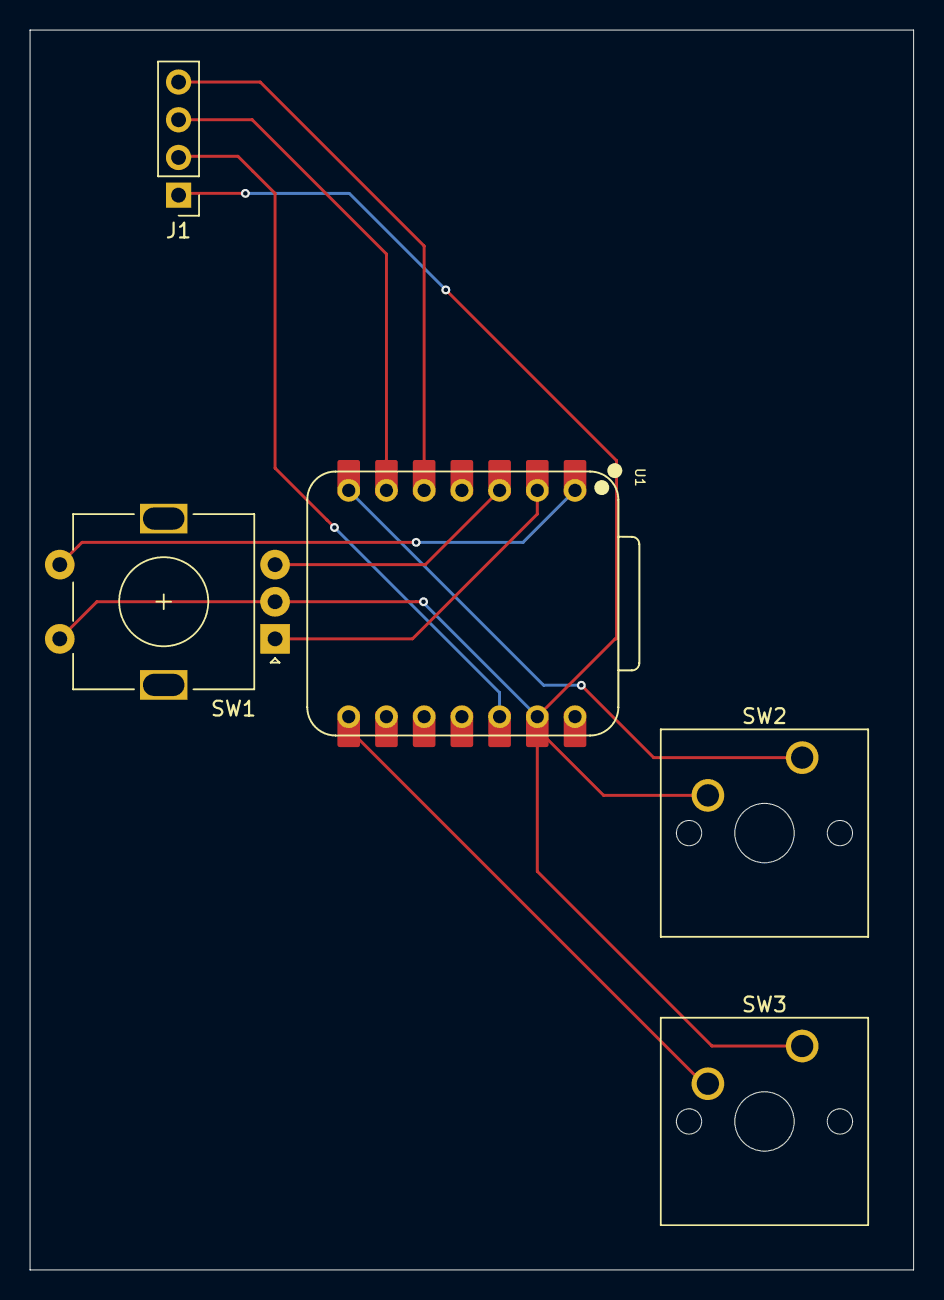
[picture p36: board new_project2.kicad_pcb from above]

Board: 2 copper layers, 59.5 x 83.5 mm, 5 parts (0 on the bottom side), 9 nets.

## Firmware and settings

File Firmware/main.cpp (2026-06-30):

#include <Arduino.h>
#include <Wire.h>
#include <WiFi.h>
#include <Adafruit_GFX.h>
#include <Adafruit_SSD1306.h>
#include <esp_sleep.h>
#include <esp_system.h>

#define ENABLE_BLE_SCAN 1

#if ENABLE_BLE_SCAN
#include <BLEDevice.h>
#endif

#define I2C_SDA 5
#define I2C_SCL 6

#define Encoder_Button_S1 1
#define Encoder_A 2
#define Encoder_B 3

#define SW2 43
#define SW3 44

#define SCREEN_WIDTH 128
#define SCREEN_HEIGHT 64
#define OLED_ADDR_1 0x3C
#define OLED_ADDR_2 0x3D

#define BATTERY_ADC_PIN -1
#define BATTERY_DIVIDER_RATIO 2.0f

const unsigned long DEBOUNCE_MS = 35;
const unsigned long LONG_PRESS_MS = 650;
const int MENU_VISIBLE_ROWS = 4;

Adafruit_SSD1306 display(SCREEN_WIDTH, SCREEN_HEIGHT, &Wire, -1);

struct ButtonState {
  uint8_t pin;
  bool reading;
  bool stable;
  unsigned long lastEdgeMs;
  unsigned long pressedAtMs;
  bool shortPress;
  bool longPress;
  bool longSent;
};

enum InputAction {
  ACT_NONE,
  ACT_UP,
  ACT_DOWN,
  ACT_SELECT,
  ACT_BACK
};

struct BleResult {
  String name;
  String address;
  int rssi;
};

void runWiFiScan();
void runWiFiAnalyzer();
void runBleScan();
void runSoftAPDemo();
void showSysInfo();
void runI2CScan();
void runGpioMonitor();
void runDisplayTest();
void runDeepSleep();
void showAbout();

typedef void (*MenuHandler)();

struct MenuItem {
  const char *label;
  MenuHandler handler;
};

MenuItem menuItems[] = {
  {"WiFi Scan", runWiFiScan},
  {"WiFi Analyzer", runWiFiAnalyzer},
  {"BLE Scan", runBleScan},
  {"SoftAP Demo", runSoftAPDemo},
  {"Sys Info", showSysInfo},
  {"I2C Scanner", runI2CScan},
  {"GPIO Monitor", runGpioMonitor},
  {"Display Test", runDisplayTest},
  {"Sleep 10s", runDeepSleep},
  {"About / Help", showAbout}
};

const int NUM_MENU_ITEMS = sizeof(menuItems) / sizeof(menuItems[0]);

ButtonState btnSelect = {SW2, HIGH, HIGH, 0, 0, false, false, false};
ButtonState btnNext = {SW3, HIGH, HIGH, 0, 0, false, false, false};
ButtonState btnEncoder = {Encoder_Button_S1, HIGH, HIGH, 0, 0, false, false, false};

int menuIndex = 0;
int menuTop = 0;
uint8_t lastEncoderState = 0;
int8_t encoderAccumulator = 0;
bool encoderSeen = false;

const int MAX_BLE_RESULTS = 12;
BleResult bleResults[MAX_BLE_RESULTS];
int bleResultCount = 0;

int clampInt(int value, int low, int high) {
  if (value < low) return low;
  if (value > high) return high;
  return value;
}

String trimText(String text, uint8_t maxChars) {
  if (text.length() <= maxChars) return text;
  if (maxChars <= 1) return "~";
  return text.substring(0, maxChars - 1) + "~";
}

void printTrimmed(String text, int x, int y, uint8_t maxChars) {
  display.setCursor(x, y);
  display.print(trimText(text, maxChars));
}

void drawHeader(String title) {
  display.fillRect(0, 0, SCREEN_WIDTH, 12, SSD1306_WHITE);
  display.setTextSize(1);
  display.setTextColor(SSD1306_BLACK);
  printTrimmed(title, 2, 2, 16);
  display.setCursor(106, 2);
  display.print(encoderSeen ? "ENC" : "BTN");
  display.setTextColor(SSD1306_WHITE);
}

void drawFooter(String left, String right) {
  display.drawFastHLine(0, 54, SCREEN_WIDTH, SSD1306_WHITE);
  display.setTextSize(1);
  display.setTextColor(SSD1306_WHITE);
  display.setCursor(0, 56);
  display.print(trimText(left, 13));
  if (right.length() > 0) {
    int x = SCREEN_WIDTH - (right.length() * 6);
    if (x < 58) x = 58;
    display.setCursor(x, 56);
    display.print(trimText(right, 11));
  }
}

void centerText(String text, int y, uint8_t size) {
  int16_t x1, y1;
  uint16_t w, h;
  display.setTextSize(size);
  display.getTextBounds(text, 0, y, &x1, &y1, &w, &h);
  display.setCursor((SCREEN_WIDTH - w) / 2, y);
  display.print(text);
  display.setTextSize(1);
}

void drawScrollBar(int topIndex, int total, int visible, int y, int h) {
  if (total <= visible) return;
  int thumbH = max(6, (h * visible) / total);
  int range = total - visible;
  int thumbY = y + ((h - thumbH) * topIndex) / range;
  display.drawFastVLine(126, y, h, SSD1306_WHITE);
  display.fillRect(124, thumbY, 4, thumbH, SSD1306_WHITE);
}

void showBusy(String title, String line1, String line2 = "") {
  display.clearDisplay();
  drawHeader(title);
  display.setCursor(0, 22);
  display.print(line1);
  if (line2.length() > 0) {
    display.setCursor(0, 34);
    display.print(line2);
  }
  display.display();
}

void adjustTopForSelection(int selected, int &top, int total, int visible) {
  if (selected < top) top = selected;
  if (selected >= top + visible) top = selected - visible + 1;
  top = clampInt(top, 0, max(0, total - visible));
}

void initButton(ButtonState &button) {
  bool value = digitalRead(button.pin);
  button.reading = value;
  button.stable = value;
  button.lastEdgeMs = millis();
  button.pressedAtMs = 0;
  button.shortPress = false;
  button.longPress = false;
  button.longSent = false;
}

void updateButton(ButtonState &button) {
  bool value = digitalRead(button.pin);
  unsigned long now = millis();

  if (value != button.reading) {
    button.reading = value;
    button.lastEdgeMs = now;
  }

  if ((now - button.lastEdgeMs) > DEBOUNCE_MS && value != button.stable) {
    button.stable = value;
    if (button.stable == LOW) {
      button.pressedAtMs = now;
      button.longSent = false;
    } else {
      if (!button.longSent) button.shortPress = true;
    }
  }

  if (button.stable == LOW && !button.longSent &&
      (now - button.pressedAtMs) > LONG_PRESS_MS) {
    button.longPress = true;
    button.longSent = true;
  }
}

bool takeShort(ButtonState &button) {
  if (!button.shortPress) return false;
  button.shortPress = false;
  return true;
}

bool takeLong(ButtonState &button) {
  if (!button.longPress) return false;
  button.longPress = false;
  return true;
}

void clearButtonEvents(ButtonState &button) {
  button.shortPress = false;
  button.longPress = false;
}

void pollControls() {
  updateButton(btnSelect);
  updateButton(btnNext);
  updateButton(btnEncoder);
}

int8_t readEncoderStep() {
  static const int8_t table[16] = {
    0, -1, 1, 0,
    1, 0, 0, -1,
    -1, 0, 0, 1,
    0, 1, -1, 0
  };

  uint8_t current = (digitalRead(Encoder_A) << 1) | digitalRead(Encoder_B);
  if (current == lastEncoderState) return 0;

  uint8_t transition = (lastEncoderState << 2) | current;
  lastEncoderState = current;
  encoderAccumulator += table[transition];

  if (encoderAccumulator >= 4) {
    encoderAccumulator = 0;
    encoderSeen = true;
    return 1;
  }
  if (encoderAccumulator <= -4) {
    encoderAccumulator = 0;
    encoderSeen = true;
    return -1;
  }
  return 0;
}

InputAction readInputAction(bool buttonScroll = true) {
  pollControls();

  int8_t encoderStep = readEncoderStep();
  if (encoderStep > 0) return ACT_DOWN;
  if (encoderStep < 0) return ACT_UP;

  if (takeShort(btnEncoder) || takeShort(btnSelect)) return ACT_SELECT;
  if (takeLong(btnEncoder) || takeLong(btnSelect)) return ACT_BACK;

  if (buttonScroll) {
    if (takeShort(btnNext)) return ACT_DOWN;
    if (takeLong(btnNext)) return ACT_UP;
  } else {
    if (takeShort(btnNext) || takeLong(btnNext)) return ACT_BACK;
  }

  return ACT_NONE;
}

void showBootScreen() {
  display.clearDisplay();
  display.drawRect(0, 0, SCREEN_WIDTH, SCREEN_HEIGHT, SSD1306_WHITE);
  display.drawRect(2, 2, SCREEN_WIDTH - 4, SCREEN_HEIGHT - 4, SSD1306_WHITE);

  centerText("XIAO", 12, 2);
  centerText("TOOLKIT", 31, 2);
  display.setTextSize(1);
  display.setCursor(18, 52);
  display.print("OLED 0.96 / ESP32S3");
  display.display();
  delay(1200);
}

void drawMenu() {
  adjustTopForSelection(menuIndex, menuTop, NUM_MENU_ITEMS, MENU_VISIBLE_ROWS);

  display.clearDisplay();
  drawHeader("XIAO Tools");

  for (int row = 0; row < MENU_VISIBLE_ROWS; row++) {
    int item = menuTop + row;
    int y = 15 + row * 10;
    if (item >= NUM_MENU_ITEMS) break;

    bool selected = item == menuIndex;
    if (selected) {
      display.fillRect(0, y - 1, 123, 10, SSD1306_WHITE);
      display.setTextColor(SSD1306_BLACK);
    } else {
      display.setTextColor(SSD1306_WHITE);
    }

    display.setCursor(2, y);
    display.print(selected ? ">" : " ");
    printTrimmed(menuItems[item].label, 12, y, 17);
  }

  display.setTextColor(SSD1306_WHITE);
  drawScrollBar(menuTop, NUM_MENU_ITEMS, MENU_VISIBLE_ROWS, 14, 38);
  drawFooter("SW3 move", "SW2 open");
  display.display();
}

String authModeToString(wifi_auth_mode_t type) {
  switch (type) {
    case WIFI_AUTH_OPEN: return "OPEN";
    case WIFI_AUTH_WEP: return "WEP";
    case WIFI_AUTH_WPA_PSK: return "WPA";
    case WIFI_AUTH_WPA2_PSK: return "WPA2";
    case WIFI_AUTH_WPA_WPA2_PSK: return "WPA/WPA2";
    case WIFI_AUTH_WPA2_ENTERPRISE: return "WPA2-E";
    case WIFI_AUTH_WPA3_PSK: return "WPA3";
    case WIFI_AUTH_WPA2_WPA3_PSK: return "WPA2/3";
    default: return "SEC";
  }
}

String wifiNameAt(int index) {
  String ssid = WiFi.SSID(index);
  if (ssid.length() == 0) ssid = "(hidden)";
  return ssid;
}

void drawWifiList(int count, int selected, int top) {
  display.clearDisplay();
  drawHeader(String("WiFi ") + count);

  if (count <= 0) {
    display.setCursor(0, 28);
    display.print("No networks found.");
    drawFooter("SW2 rescan", "hold back");
    display.display();
    return;
  }

  int visible = min(MENU_VISIBLE_ROWS, count);
  for (int row = 0; row < visible; row++) {
    int item = top + row;
    int y = 15 + row * 10;
    bool isSelected = item == selected;

    if (isSelected) {
      display.fillRect(0, y - 1, 123, 10, SSD1306_WHITE);
      display.setTextColor(SSD1306_BLACK);
    } else {
      display.setTextColor(SSD1306_WHITE);
    }

    printTrimmed(wifiNameAt(item), 1, y, 12);
    display.setCursor(78, y);
    display.print(WiFi.RSSI(item));
    display.setCursor(106, y);
    display.print("ch");
    display.print(WiFi.channel(item));
  }

  display.setTextColor(SSD1306_WHITE);
  drawScrollBar(top, count, MENU_VISIBLE_ROWS, 14, 38);
  drawFooter("SW2 detail", "hold back");
  display.display();
}

void showWifiDetail(int index) {
  while (true) {
    display.clearDisplay();
    drawHeader("WiFi Detail");
    display.setTextColor(SSD1306_WHITE);

    display.setCursor(0, 15);
    display.print("SSID ");
    printTrimmed(wifiNameAt(index), 30, 15, 16);

    display.setCursor(0, 25);
    display.print("RSSI ");
    display.print(WiFi.RSSI(index));
    display.print(" dBm");

    display.setCursor(0, 35);
    display.print("CH ");
    display.print(WiFi.channel(index));
    display.print("  ");
    display.print(authModeToString(WiFi.encryptionType(index)));

    display.setCursor(0, 45);
    display.print(WiFi.BSSIDstr(index));

    drawFooter("SW2 back", "");
    display.display();

    InputAction action = readInputAction(false);
    if (action == ACT_SELECT || action == ACT_BACK) return;
    delay(20);
  }
}

void runWiFiScan() {
  WiFi.mode(WIFI_STA);
  WiFi.disconnect();
  delay(100);

  while (true) {
    showBusy("WiFi Scan", "Scanning 2.4 GHz...");
    int count = WiFi.scanNetworks(false, true);
    int selected = 0;
    int top = 0;

    while (true) {
      if (count > 0) {
        selected = clampInt(selected, 0, count - 1);
        adjustTopForSelection(selected, top, count, MENU_VISIBLE_ROWS);
      }
      drawWifiList(count, selected, top);

      InputAction action = readInputAction(true);
      if (action == ACT_DOWN && count > 0) selected = (selected + 1) % count;
      if (action == ACT_UP && count > 0) selected = (selected + count - 1) % count;
      if (action == ACT_SELECT) {
        if (count > 0) showWifiDetail(selected);
        else break;
      }
      if (action == ACT_BACK) {
        WiFi.scanDelete();
        return;
      }
      delay(20);
    }

    WiFi.scanDelete();
  }
}

void drawChannelAnalyzer(int counts[15], int totalNetworks, int maxCount) {
  display.clearDisplay();
  drawHeader("WiFi Analyzer");

  display.setCursor(0, 14);
  display.print("APs ");
  display.print(totalNetworks);
  display.print("  max ");
  display.print(maxCount);

  int baseY = 51;
  display.drawFastHLine(0, baseY, 122, SSD1306_WHITE);
  for (int ch = 1; ch <= 13; ch++) {
    int x = 2 + (ch - 1) * 9;
    int h = (maxCount == 0) ? 0 : map(counts[ch], 0, maxCount, 0, 27);
    display.fillRect(x, baseY - h, 6, h, SSD1306_WHITE);
    if (ch % 2 == 1) {
      display.setCursor(x, 43);
      display.print(ch);
    }
  }

  drawFooter("SW2 rescan", "hold back");
  display.display();
}

void scanChannels(int counts[15], int &totalNetworks, int &maxCount) {
  for (int i = 0; i < 15; i++) counts[i] = 0;

  WiFi.mode(WIFI_STA);
  WiFi.disconnect();
  delay(100);

  totalNetworks = WiFi.scanNetworks(false, true);
  maxCount = 0;
  for (int i = 0; i < totalNetworks; i++) {
    int ch = WiFi.channel(i);
    if (ch >= 1 && ch <= 14) {
      counts[ch]++;
      if (counts[ch] > maxCount) maxCount = counts[ch];
    }
  }
  WiFi.scanDelete();
}

void runWiFiAnalyzer() {
  int counts[15];
  int totalNetworks = 0;
  int maxCount = 0;

  while (true) {
    showBusy("WiFi Analyzer", "Scanning channels...");
    scanChannels(counts, totalNetworks, maxCount);

    while (true) {
      drawChannelAnalyzer(counts, totalNetworks, maxCount);
      InputAction action = readInputAction(false);
      if (action == ACT_SELECT) break;
      if (action == ACT_BACK) return;
      delay(20);
    }
  }
}

void sortBleByRssi() {
  for (int i = 0; i < bleResultCount - 1; i++) {
    for (int j = i + 1; j < bleResultCount; j++) {
      if (bleResults[j].rssi > bleResults[i].rssi) {
        BleResult tmp = bleResults[i];
        bleResults[i] = bleResults[j];
        bleResults[j] = tmp;
      }
    }
  }
}

void collectBleResults() {
  bleResultCount = 0;

#if ENABLE_BLE_SCAN
  BLEDevice::init("");
  BLEScan *scan = BLEDevice::getScan();
  scan->setActiveScan(true);
  scan->setInterval(100);
  scan->setWindow(80);

#if defined(ESP_ARDUINO_VERSION_MAJOR) && ESP_ARDUINO_VERSION_MAJOR >= 3
  BLEScanResults *found = scan->start(4, false);
  int total = found ? found->getCount() : 0;
  for (int i = 0; i < total && bleResultCount < MAX_BLE_RESULTS; i++) {
    BLEAdvertisedDevice dev = found->getDevice(i);
#else
  BLEScanResults found = scan->start(4, false);
  int total = found.getCount();
  for (int i = 0; i < total && bleResultCount < MAX_BLE_RESULTS; i++) {
    BLEAdvertisedDevice dev = found.getDevice(i);
#endif
    String name = dev.haveName() ? String(dev.getName().c_str()) : String("(no name)");
    bleResults[bleResultCount].name = name;
    bleResults[bleResultCount].address = String(dev.getAddress().toString().c_str());
    bleResults[bleResultCount].rssi = dev.getRSSI();
    bleResultCount++;
  }

  sortBleByRssi();
  scan->clearResults();
  BLEDevice::deinit(true);
#endif
}

void drawBleList(int selected, int top) {
  display.clearDisplay();
  drawHeader(String("BLE ") + bleResultCount);

#if !ENABLE_BLE_SCAN
  display.setCursor(0, 24);
  display.print("BLE disabled.");
  display.setCursor(0, 36);
  display.print("Set ENABLE_BLE_SCAN 1");
  drawFooter("SW2 back", "");
  display.display();
  return;
#else
  if (bleResultCount == 0) {
    display.setCursor(0, 26);
    display.print("No BLE devices.");
    drawFooter("SW2 rescan", "hold back");
    display.display();
    return;
  }

  int visible = min(MENU_VISIBLE_ROWS, bleResultCount);
  for (int row = 0; row < visible; row++) {
    int item = top + row;
    int y = 15 + row * 10;
    bool isSelected = item == selected;
    if (isSelected) {
      display.fillRect(0, y - 1, 123, 10, SSD1306_WHITE);
      display.setTextColor(SSD1306_BLACK);
    } else {
      display.setTextColor(SSD1306_WHITE);
    }
    printTrimmed(bleResults[item].name, 1, y, 14);
    display.setCursor(90, y);
    display.print(bleResults[item].rssi);
  }
  display.setTextColor(SSD1306_WHITE);
  drawScrollBar(top, bleResultCount, MENU_VISIBLE_ROWS, 14, 38);
  drawFooter("SW2 detail", "hold back");
  display.display();
#endif
}

void showBleDetail(int index) {
  while (true) {
    display.clearDisplay();
    drawHeader("BLE Detail");
    display.setCursor(0, 15);
    display.print("Name ");
    printTrimmed(bleResults[index].name, 30, 15, 16);
    display.setCursor(0, 28);
    display.print("RSSI ");
    display.print(bleResults[index].rssi);
    display.print(" dBm");
    display.setCursor(0, 41);
    printTrimmed(bleResults[index].address, 0, 41, 21);
    drawFooter("SW2 back", "");
    display.display();

    InputAction action = readInputAction(false);
    if (action == ACT_SELECT || action == ACT_BACK) return;
    delay(20);
  }
}

void runBleScan() {
#if !ENABLE_BLE_SCAN
  drawBleList(0, 0);
  while (true) {
    InputAction action = readInputAction(false);
    if (action == ACT_SELECT || action == ACT_BACK) return;
    delay(20);
  }
#else
  while (true) {
    showBusy("BLE Scan", "Scanning BLE...", "4 seconds");
    collectBleResults();
    int selected = 0;
    int top = 0;

    while (true) {
      if (bleResultCount > 0) {
        selected = clampInt(selected, 0, bleResultCount - 1);
        adjustTopForSelection(selected, top, bleResultCount, MENU_VISIBLE_ROWS);
      }
      drawBleList(selected, top);

      InputAction action = readInputAction(true);
      if (action == ACT_DOWN && bleResultCount > 0) selected = (selected + 1) % bleResultCount;
      if (action == ACT_UP && bleResultCount > 0) selected = (selected + bleResultCount - 1) % bleResultCount;
      if (action == ACT_SELECT) {
        if (bleResultCount > 0) showBleDetail(selected);
        else break;
      }
      if (action == ACT_BACK) return;
      delay(20);
    }
  }
#endif
}

void runSoftAPDemo() {
  const char *apSsid = "XIAO-TOOLS";
  const char *apPass = "12345678";

  WiFi.mode(WIFI_AP_STA);
  bool ok = WiFi.softAP(apSsid, apPass, 1, false, 4);

  while (true) {
    display.clearDisplay();
    drawHeader("SoftAP Demo");
    if (!ok) {
      display.setCursor(0, 24);
      display.print("AP start failed.");
    } else {
      display.setCursor(0, 15);
      display.print("SSID ");
      display.print(apSsid);
      display.setCursor(0, 25);
      display.print("PASS ");
      display.print(apPass);
      display.setCursor(0, 35);
      display.print("IP ");
      display.print(WiFi.softAPIP());
      display.setCursor(0, 45);
      display.print("Clients ");
      display.print(WiFi.softAPgetStationNum());
    }
    drawFooter("SW2 stop", "");
    display.display();

    InputAction action = readInputAction(false);
    if (action == ACT_SELECT || action == ACT_BACK) break;
    delay(250);
  }

  WiFi.softAPdisconnect(true);
  WiFi.mode(WIFI_STA);
}

String resetReasonToString(esp_reset_reason_t reason) {
  switch (reason) {
    case ESP_RST_POWERON: return "POWERON";
    case ESP_RST_EXT: return "EXT";
    case ESP_RST_SW: return "SW";
    case ESP_RST_PANIC: return "PANIC";
    case ESP_RST_INT_WDT: return "INT WDT";
    case ESP_RST_TASK_WDT: return "TASK WDT";
    case ESP_RST_WDT: return "WDT";
    case ESP_RST_DEEPSLEEP: return "DEEPSLEEP";
    case ESP_RST_BROWNOUT: return "BROWNOUT";
    case ESP_RST_SDIO: return "SDIO";
    default: return "UNKNOWN";
  }
}

String kb(uint32_t bytes) {
  return String(bytes / 1024) + " KB";
}

void drawSysInfoPage(int page) {
  display.clearDisplay();
  drawHeader(String("Sys Info ") + (page + 1) + "/4");

  if (page == 0) {
    display.setCursor(0, 15);
    display.print("Chip ");
    display.print(ESP.getChipModel());
    display.setCursor(0, 25);
    display.print("Cores ");
    display.print(ESP.getChipCores());
    display.print(" Rev ");
    display.print(ESP.getChipRevision());
    display.setCursor(0, 35);
    display.print("CPU ");
    display.print(getCpuFrequencyMhz());
    display.print(" MHz");
    display.setCursor(0, 45);
    display.print("SDK ");
    printTrimmed(String(ESP.getSdkVersion()), 25, 45, 16);
  } else if (page == 1) {
    display.setCursor(0, 15);
    display.print("Heap ");
    display.print(kb(ESP.getFreeHeap()));
    display.setCursor(0, 25);
    display.print("Min ");
    display.print(kb(ESP.getMinFreeHeap()));
    display.setCursor(0, 35);
    display.print("Max block ");
    display.print(kb(ESP.getMaxAllocHeap()));
    display.setCursor(0, 45);
    display.print("PSRAM ");
    display.print(psramFound() ? kb(ESP.getFreePsram()) : "none");
  } else if (page == 2) {
    display.setCursor(0, 15);
    display.print("Flash ");
    display.print(kb(ESP.getFlashChipSize()));
    display.setCursor(0, 25);
    display.print("Sketch ");
    display.print(kb(ESP.getSketchSize()));
    display.setCursor(0, 35);
    display.print("Free OTA ");
    display.print(kb(ESP.getFreeSketchSpace()));
    display.setCursor(0, 45);
    printTrimmed(WiFi.macAddress(), 0, 45, 21);
  } else {
    display.setCursor(0, 15);
    display.print("Uptime ");
    display.print(millis() / 1000);
    display.print(" s");
    display.setCursor(0, 25);
    display.print("Temp ");
    display.print(temperatureRead(), 1);
    display.print(" C");
    display.setCursor(0, 35);
    display.print("Reset ");
    display.print(resetReasonToString(esp_reset_reason()));
#if BATTERY_ADC_PIN >= 0
    int raw = analogRead(BATTERY_ADC_PIN);
    float volts = (raw / 4095.0f) * 3.3f * BATTERY_DIVIDER_RATIO;
    display.setCursor(0, 45);
    display.print("BAT ");
    display.print(volts, 2);
    display.print(" V");
#else
    display.setCursor(0, 45);
    display.print("Battery ADC off");
#endif
  }

  drawFooter("SW3 page", "SW2 back");
  display.display();
}
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
void loop() {
  InputAction action = readInputAction(true);

  if (action == ACT_DOWN) {
    menuIndex = (menuIndex + 1) % NUM_MENU_ITEMS;
    drawMenu();
  } else if (action == ACT_UP) {
    menuIndex = (menuIndex + NUM_MENU_ITEMS - 1) % NUM_MENU_ITEMS;
    drawMenu();
  } else if (action == ACT_SELECT) {
    display.clearDisplay();
    showBusy("Opening", menuItems[menuIndex].label);
    delay(120);
    menuItems[menuIndex].handler();
    clearButtonEvents(btnSelect);
    clearButtonEvents(btnNext);
    clearButtonEvents(btnEncoder);
    drawMenu();
  }

  delay(10);
}
}

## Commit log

2026-01-19 PCB schematic kicad
2026-01-19 marauder_master
    contains gbr and gbrjob files and the pdf schematic
2026-01-21 Add assembly preview to README
    Added assembly preview section with images.
2026-07-02 Document project journals in README
    Added detailed journal entries documenting the soldering, assembly, and firmware development process for the ESP32-S3 project, including challenges faced and solutions implemented.
2026-07-02 Revise BOM and firmware details in README
    Updated the BOM section to reflect the use of Seeed XIAO ESP32 S3 instead of RP2040 due to delivery issues. Added details about the firmware and its capabilities.
2026-07-02 Revise build preview and update microcontroller details
    Updated the build preview section and changed the microcontroller reference in the BOM.
2026-07-02 Enhance README with firmware and BOM updates
    Updated the README to include details about the firmware, hardware components, and changes in the BOM due to customs issues.
2026-07-02 Update README with BOM and device information
    Clarified details about the BOM and device used in the project.
2026-07-02 Revise BOM with updated components and links
    Updated the Bill of Materials (BOM) to reflect component changes due to delivery issues, including switching from XIAO RP2040 to XIAO ESP32S3 and updating display specifications.
2026-07-02 Revise BOM format with additional details
    Updated the Bill of Materials (BOM) section to include additional details such as quantity, purpose, price, and links for each component.
2026-07-02 Enhance README with project overview and BOM details
    Updated the README to include project details, firmware functionality, and changes in components used.
2026-07-02 Revise BOM information and device details in README
    Updated BOM links in README and clarified device differences.
2026-07-02 Create BOM.csv with component details
    Added a Bill of Materials (BOM) listing components, quantities, descriptions, prices, and links.
    [BOM.csv]
2026-07-02 Update README with new image and firmware details
    Added an image of the Arduino test to the README and expanded on the firmware development process, detailing the custom UI system and features implemented.
2026-07-02 Enhance README with images and BOM updates
    Updated README with additional images and BOM links, clarified device compatibility.
2026-07-02 Update 3D Printed Case supplier in README
2026-07-02 Add case improvisation image to README
    Added a new image for case improvisation to the README.
2026-07-02 Revise BOM links and clarify firmware compatibility
    Updated the BOM section in README with new links due to delivery issues.
2026-07-02 Convert BOM.csv to Markdown table format
    Updated BOM format to Markdown table for better readability.
    [BOM.csv]
2026-07-02 Convert BOM.csv to standard CSV format
    Updated BOM.csv to use CSV format and removed Markdown syntax.
    [BOM.csv]
2026-07-02 Fix formatting and update descriptions in BOM.csv
    Updated BOM.csv to correct formatting and improve clarity of component descriptions.
    [BOM.csv]
2026-07-02 Revise journal entries and BOM details in README
    Clarified journal entries and updated BOM links in README.
2026-07-02 Remove Arduino image from README
    Removed an image preview from the README and updated the firmware writing section.
